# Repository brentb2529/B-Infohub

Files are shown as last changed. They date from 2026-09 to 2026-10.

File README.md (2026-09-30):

# B-Infohub

**Local telemetry from a Briggs & Stratton standby generator — no subscription, no cell modem, no cloud.**

A small ESP32 board that plugs into the RS-485 port your generator already has and
speaks Modbus to its GC-1030/1031/1032 controller directly. Home Assistant gets the
readings in about a second, over your own network.

> The InfoHub is not decoding anything proprietary. It is a Modbus master with a cell
> modem and a billing relationship attached. This becomes the master instead — and you
> can keep the InfoHub connected alongside it if you want the cellular path as backup.

---

## What you get

| | EnergyTrak cloud | B-Infohub |
| --- | --- | --- |
| Readings | 34 | **130+** |
| Freshness | minutes | **~1 second** |
| Faults | one "fault" flag | **34 individually decoded alarms** |
| Works without internet | no | **yes** |
| Subscription | yes | no |

Per-leg voltages and currents, kW / kVA / kVAr, power factor, cumulative energy,
coolant temperature, battery voltage, engine RPM and hours, lifetime starts and trips,
the raw controller status word, and each fault condition as its own entity you can
automate on.

It also records alarms to onboard flash, so a fault that happens while Home Assistant
is down or the network is out is still reported when things come back — the one case
cloud monitoring cannot cover.

## What you need

- A Briggs & Stratton standby generator with a **GC-1030, GC-1031 or GC-1032**
  controller (check the label on the panel).
- A **B-Infohub board** — see [Getting the hardware](#getting-the-hardware).
- Home Assistant, with [HACS](https://hacs.xyz) installed.
- A Chrome or Edge browser on a desktop, once, to flash the board.

No soldering. No toolchain. No command line.

## Install

### 1. Flash the board

Connect it to your computer with a **data** USB cable and open the installer:

### → **[Install B-Infohub](https://brentb2529.github.io/B-Infohub/)**

Click Connect, pick the serial port, and wait. The page will then ask for your Wi-Fi.

<sub>A charge-only USB cable is the most common reason nothing appears in the port list —
it powers the board but carries no data, so the board looks dead to the browser while its
power light is on. Web Serial needs Chrome or Edge; Safari and Firefox do not implement it.</sub>

### 2. Wire it to the generator

**Switch the generator to OFF at the panel first.** Two wires, into the RS-485
terminals the controller already exposes — [wiring guide](docs/wiring.md), including
where the terminals are on each controller and how to keep an existing InfoHub
connected at the same time.

### 3. Add it to Home Assistant

Install the **[EnergyTrak integration](https://github.com/brentb2529/ha-energytrak)**
from HACS, then **Settings → Devices & Services → Add Integration → EnergyTrak**.

The bridge is discovered automatically if it is on the same subnet. On a routed or
VLAN'd network — which includes most setups where the generator is on a different
segment — choose **Local B-Infohub bridge** and enter its IP.

You do **not** need an EnergyTrak account. The integration supports three shapes:

- **Bridge only** — no subscription at all
- **Cloud only** — the original behaviour, no hardware
- **Both** — the bridge is used while it is healthy, and the cloud takes over
  automatically if it is not

## Getting the hardware

The board is built in small batches and is **not sold through a shop**. If you want
one, open a [GitHub issue](https://github.com/brentb2529/B-Infohub/issues) or get in
touch — see the ordering note below.

<!-- ORDERING DETAILS: fill these in before publishing.
     - How should people contact you (issue / email / form)?
     - What is supplied: bare PCB, assembled board, assembled + enclosure?
     - Price, and whether shipping is US-only.
     - Any lead time or batch-size caveat. -->

> **Ordering:** _contact details and what is supplied to be filled in._

Everything needed to have one made independently is in this repository —
schematic, layout, gerbers and a JLCPCB-ready fab package in
[`hardware/pcb/`](hardware/pcb/) — and the firmware is MIT licensed. Buying a board
is a convenience, not a requirement.

## It learns the generator it is plugged into

On first healthy contact the bridge probes the controller once — what it
answers, which alarm inputs are wired — and publishes a **Controller
Profile**. Home Assistant shows the learned family as the device model,
plus *Registers present*, *Alarm inputs indeterminate* and *Commissioned*.
**Run Discovery** repeats it. See [`docs/discovery.md`](docs/discovery.md).

## If something looks wrong

The bridge reports its own health, because a monitor that fails silently is worse
than no monitor:

| Entity | What it means when it is unhappy |
| --- | --- |
| **Bridge reachable** | the board is not answering Home Assistant — power or Wi-Fi |
| **Generator answering bus** | the board is fine; the generator has gone quiet on RS-485 |
| **Controller clock age** | the controller is answering but its clock has stopped — it has hung |
| **Bridge silence** | the board holds its connection but has stopped sending |
| **Wi-Fi Signal** | below about −72 dBm an ESP32 stays associated but cannot be reached |

Those are deliberately five separate signals rather than one "online" flag. They fail
independently and each one points at a different place to look.

There are also five LEDs on the board readable through the lid, which is all you have
standing at the generator with no phone signal. [How to read
them](docs/bring-up.md#status-leds).

## Documentation

| | |
| --- | --- |
| [Wiring](docs/wiring.md) | terminals, cable, termination, keeping the InfoHub |
| [Bring-up](docs/bring-up.md) | first boot, LEDs, proving the bus |
| [Register map](docs/register-map.md) | every address, what it means, what it returns |
| [Field findings](docs/field-findings-2026-08-31.md) | what a real controller actually answers |
| [Development](docs/development.md) | building the firmware, the contract, the tooling |

## Safety and scope

A standby generator is life-safety equipment. This is a **read-only monitor**: it does
not start, stop, or configure anything, and engine control is deliberately not
implemented.

Do not rely on it as your only alerting for anything that matters. It is unofficial,
unaffiliated with Briggs & Stratton, and provided as-is under the MIT licence with no
warranty. Wiring anything into a generator is your responsibility; if you are not
comfortable working in the panel, have an electrician do it.

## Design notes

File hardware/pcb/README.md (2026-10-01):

# B-Infohub Bridge v1.1 — PCB

90 × 92 mm, 2-layer, 1.6 mm FR4. KiCad 10 project generated programmatically from
`tools/circuit.py` and verified with `kicad-cli` 10.0.5.

> **Rev 1.1 (2026-10-01) is the current design**: schematic, board, routing, BOM,
> gerbers and the checks below are all rev 1.1. **It fits the rev 1.0 enclosure
> unchanged** — same outline, same six M3 holes, same three terminals on the top
> edge, same LED light-pipe positions. What changed, and why, is in *Rev 1.1*
> below. Rev 1.0 is the fielded board (one unit, running since 2026-09); its files
> are in git history at tag `pcb-rev1.0`.

## Rev 1.1

| Change | Why |
| --- | --- |
| **ESP32-WROOM-32E-H4 soldered**, replacing the socketed DevKitC | Heat. The fielded unit's die ran 125–135 °F at night and 188 °F in afternoon sun, and at 188 °F the controller link dropped a byte per reply (see *Heat*). The -H4 is the −40…+105 °C grade (the plain -32E is rated to 85 °C — the temperature this board has already reached). The DevKit's AMS1117 (5→3.3 V linear, ~0.3 W inside the module footprint) is gone; the module sits on a via-stitched ground pad. |
| **DE pull-downs** (R16/R17, EE review) | The SP3485's DE input has no pull-down and the ESP's GPIOs float from reset until the firmware runs — and for the whole of a J6 first flash. 10 k on each DE keeps both transceivers in receive, so the board can never drive the generator's bus uncommanded. Rev 1.0 is fielded without them. |
| **Single 3.3 V rail** from an AP63203 | The 5 V rail only ever fed that LDO and the PWR LED. Same buck family, pinout and application circuit as the AP63205 it replaces. |
| **Remote-antenna option**: the same pads take the **-32UE** (U.FL) | Antenna end faces the board edge, so only the enclosure wall is in front of it. Order -32E for the internal antenna; -32UE plus a U.FL→SMA bulkhead pigtail if the box is metal or the signal is poor. |
| **J5 fan header**, 12 V PWM (IO32 → AO3400A), 0.5 A polyfuse, SS14 flyback | Only if shading and venting the enclosure are not enough. Firmware `packages/fan.yaml` runs it from the die temperature, Home Assistant or not. |
| **EN/IO0 support, RESET + BOOT buttons, J6 programming header** | A bare module has no USB bridge; J6 is the one USB-serial flash it ever needs. OTA after that, as before. |
| **R10/R11** fail-safe bias on the InfoHub pair | Carried from the 2026-09-28 source-only change — see *Termination*. |
| LED series resistors moved 75 → 77.5 mm; J4 moved to the left edge | Clearing the module's pad row and the antenna region. LEDs themselves have not moved. |

Replaces the Briggs & Stratton InfoHub as the Modbus master on the GC-1032's RS-485
bus, **while passing the InfoHub through on a second port** so its cell modem keeps
working as out-of-band backup during an outage.

| Check (rev 1.1, 2026-10-01) | Result |
| --- | --- |
| `kicad-cli sch erc --severity-all` | **0 violations** (`binfohub_bridge-erc.rpt`) |
| `kicad-cli pcb drc --severity-all --refill-zones --schematic-parity` | **0 errors, 0 unconnected, 0 parity issues** |
| Routing | **100 %**, 0.25 mm-grid A* router, 738 tracks / 109 vias, GND pour both layers **plotted into the gerbers** (see below) |
| LCSC | **36 distinct parts**, one BOM line each; the 11 parts new or changed in rev 1.1 verified in stock on 2026-10-01, the rest last checked 2026-08-31 |

Remaining DRC output is a handful of warnings: short dangling tails on hand-routed
escape stubs the router joined part-way along (low-speed lines, verified
electrically meaningless in the EE review), and `lib_footprint_mismatch` on the
terminal blocks (locating pegs deliberately stripped, see ORDER.md) and on U1
(the project copy of the WROOM footprint, identical to the library on every
pad, via and keepout). **No silk over any pad, no courtyard overlaps.** The exact
counts are in `binfohub_bridge-drc.rpt`.

**EE review (2026-10-01):** independent pre-fab review of the full source; verdict
*green after fixes*, all applied — -H4 module, DE pull-downs, 680 Ω bias, 1.1 A fan
fuse, 100 nF moved to the VDD pad, BOM grouping by part, JLC gerber layer set.
Confirmed clean: every pin against the firmware map, no strapping pins, EN/IO0
reference circuit, buck pinout and FB, D10/Q2 polarity, SM712 pin order, pour
present in the gerbers, antenna keepout honoured.

> **Rev 1.0's shipped gerbers had no ground pour.** `gen_pcb.py` writes zone
> outlines only, and the rev 1.0 plot never refilled them: the F_Cu gerber in git
> history has zero `G36` regions. The fielded board's GND is tracks only — it works,
> but it is not what the README claimed. `tools/export.sh` now plots with
> `--check-zones` and prints the region count so this cannot silently recur.

Everything is regenerated by `tools/export.sh` after `router.py` (or `rebuild.py`
for text-only changes): ERC, DRC, BOM/CPL, gerbers + drill, the JLC zip and the
previews.

## What is on it

| Block | Parts |
| --- | --- |
| **Power in** | J1 screw terminal, AO3401A reverse-polarity P-FET (4 A — carries the InfoHub too), **SMBJ16A TVS**, 100 µF bulk |
| **3.3 V rail** | AP63203WU-7 sync buck, 3.8–32 V in, fixed 3.3 V 2 A + 10 µH shielded inductor (the b-hydro / rev 1.0 circuit; the datasheet's 3.3 V example is 4.7 µH, 10 µH is the conservative side), 1.1 A polyfuse |
| **InfoHub 12 V** | Separate 2 A polyfuse (F2) |
| **Fan 12 V** | J5, separate 1.1 A / 33 V polyfuse (F3 — a PPTC derates ~40 % at box temperature, so 0.5 A would nuisance-trip), AO3400A low-side PWM switch, SS14 flyback |
| **RS-485 × 2** | SP3485EN transceivers, PSM712 TVS per pair, 120 Ω termination on jumpers (ship OPEN — see below); 680 Ω fail-safe bias R10/R11 on the InfoHub pair; 10 k pull-downs on both DE lines so neither transceiver can drive while the ESP is in reset or being flashed |
| **MCU** | ESP32-WROOM-32E**-H4** (−40…+105 °C grade) soldered, or -32UE for U.FL; 10 k/1 µF on EN, RESET and BOOT buttons, J6 programming header |
| **Indicators** | 5 LEDs (PWR / WIFI / BUS / FAULT / TX) sized for light pipes, plus J4 header |

### Why the power section is split into two fuses

Our bridge draws ~150 mA. The InfoHub's cell modem pulses to 1–2 A on transmit. Sharing
a fuse would let an InfoHub fault take down the telemetry — precisely backwards. Both
legs sit behind the same reverse-polarity FET, so a miswired harness cannot hurt either
device, but a fault in one cannot starve the other.

### Why the LED resistors are 100R / 330R and not 1k

These are driven from a 3.3 V GPIO. A blue or green LED has a forward drop near 2.9 V,
leaving ~0.4 V across the resistor — 1k would give roughly **0.5 mA**, invisible through
a light pipe. 100R for blue/green and 330R for red/yellow puts all five at about 4 mA.

## Termination: ship JP1 and JP2 OPEN

Measured, not assumed. On 2026-08-31 the live bus delivered **368 consecutive
error-free 87-register block reads** (32,016 values, every one CRC-checked) across
engine cranking and five minutes of running, with an adapter that was almost certainly
unterminated. Zero failures.

The physics agrees. At 9600 baud one bit is **104 µs**; signal propagates at ~5 ns/m,
so even a 30 m run has a 150 ns round trip — 0.14 % of a bit period. Reflections from
the SP3485's fast edges settle within a few hundred nanoseconds, while the receiver
samples in the *middle* of the bit. Termination is governed by edge rate versus cable
delay, and here there are three orders of magnitude of margin.

There is also a cost to fitting them: 120 Ω with no fail-safe biasing pulls A and B
together at idle, which can leave the receiver output indeterminate and produce framing
errors. **Adding termination to a bus that already works can make idle behaviour
worse.**

So: leave both jumpers open. Fit one only if CRC errors appear on that segment. They
exist so the option is available, not because it is needed.

If a bus ever does misbehave at idle rather than in traffic, the fix is fail-safe
biasing (pull-up on A, pull-down on B), not termination.

**Rev 1.0 has no bias footprints, and port B does misbehave at idle.** A raw-frame
capture on 2026-09-28 showed ~61 bytes of garbage arriving on the InfoHub pair 35–57 ms
after every reply the bridge sends — the pair floating inside the receiver's ±200 mV
dead band once our driver releases it. ESPHome's Modbus server reads that as an
incoming request, holds its next reply, and drops it: 8 of 36 replies to the InfoHub
in 75 s, with the InfoHub retrying after 0.8 s each time. It tolerates this (it kept
the vendor cloud fed for a week on it), but the bus is dirtier than it should be. Port
A is unaffected because the GC-1032 biases its own bus.

**Rev 1.1 adds R10/R11** (4.7 kΩ pull-up on A to 3.3 V, pull-down on B to GND, next
to U4), fitted by default. Rev 1.0 boards are left as they are by decision; the
firmware can be made tolerant of the noise (flush the port-B receive buffer after
transmitting) if a fielded board ever needs it.

## Heat — measured on the fielded unit, 2026-10-01

The ESP32 die runs **125–135 °F at night** with the air in the 50s: ~75 °F of
self-heating in a sealed box with no airflow. A clear afternoon adds **45–60 °F**
of solar gain on the enclosure (overcast days add 8–17 °F), and the peak is always
13:30–14:45 regardless of the air temperature. On 1 Oct, 80 °F air put the die at
**188 °F**; the port-A link to the GC-1032 then dropped one byte from every reply
(0 good reads for ~90 min, reproduced on a fresh boot at the same temperature) and
recovered on its own as the box cooled. 185 °F on 25 Sep had survived, so the cliff
is ~185–188 °F die. Which end of the link drifts first is not known; the SP3485EN
is industrial grade (−40…+85 °C), the controller is in the same sun.

Firmware 1.2.1 took the two biggest self-heat terms down (CPU 240→160 MHz, Wi-Fi
modem sleep): die fell 192→162 °F in four minutes in the same sun. HA automation
`binfohub_bridge_hot` warns at 175 °F. Neither is the fix; the enclosure is.

**In order of effect:**

1. **Mounting note on the enclosure and in the install guide: not in direct
   afternoon sun.** Shade (a louvered shroud, or the north side of the pad) is
   worth more than every item below combined — it is the ~55 °F term.
2. **A breathing enclosure.** The rev 1.0 box has one membrane vent, low, and
   still reached 188 °F: one vent does not convect. Add a second Gore-type vent
   **high** on the opposite wall so the box is a chimney. Passive; no moving parts
   on a box that must run through an outage.
3. **Done in rev 1.1: bare ESP32-WROOM-32E on the board, 3.3 V straight from an
   AP63203 buck.** The DevKit's AMS1117 LDO dissipated ~0.3 W dropping 5→3.3 V
   inside the module footprint; the module now sits on a via-stitched ground pad
   into the back-side pour.
4. **Fan — provided for, not fitted.** Rev 1.1 carries J5 (12 V, PWM, fused,
   flyback) so a fan can be added without a board change if 1–3 are not enough.
   A fan is a moving part, a dust and moisture path, and a load on the
   generator-side 12 V; a heatsink in still, trapped air moves heat into the same
   air. Neither is the first answer.

Acceptance test: a sunny-afternoon die peak at least 20 °F under the 175 °F
alert, i.e. the rev 1.1 unit should never page.

## Bus parameters — measured, not assumed

**Slave 10, 9600 8E1.** Not the genmon defaults (1 / 19200). Found with
`tools/gc1032_probe.py scan` on 2026-08-31 and confirmed against live readings; the
values are on the back silkscreen so nobody has to re-derive them. See
`../../docs/field-findings-2026-08-31.md`.

## Enclosure interface

The lid needs light pipes over these LED centres (board coordinates, origin = top-left):

| LED | Function | Colour | x | y |
| --- | --- | --- | --- | --- |
| D5 | PWR | green | 18.0 | 80.0 |
| D6 | WIFI | blue | 29.0 | 80.0 |
| D7 | BUS | green | 40.0 | 80.0 |
| D8 | FAULT | red | 51.0 | 80.0 |
| D9 | TX | yellow | 62.0 | 80.0 |

11 mm pitch, which suits 3 mm acrylic rod.

**Cable entry.** All three terminals sit on the **top edge (y = 7)** with their wire
openings facing outward, so one enclosure wall takes every gland. Pad spans:

| Terminal | x range |
| --- | --- |
| J1 12 V IN (2P, 5.08 mm) | 12.0 – 17.1 |
| J2 BUS (2P, 2.54 mm) | 50.0 – 52.5 |
| J3 INFOHUB (4P, 2.54 mm) | 70.0 – 77.6 |

**Terminal contents.** The generator harness carries four conductors that matter:
+12 V, GND, and the RS-485 pair. Power lands on J1, the pair lands on J2 — and J2
needs no ground pin of its own, because the harness ground is already on J1 and it is
the same net. J3 is different: it is a separate cable run out to the InfoHub carrying
power *and* data, so it needs its own return.

| | Pins | To |
| --- | --- | --- |
| J1 | +12V, GND | harness power (red/grey, black) |
| J2 | A, B | harness RS-485 pair (brown, yellow) |
| J3 | +12V, GND, A, B | the InfoHub |

**Mounting:** six M3 holes at (4.5, 4.5), (85.5, 4.5), (4.5, 46), (85.5, 46),
(4.5, 87.5), (85.5, 87.5).

## Files

| File | Purpose |
| --- | --- |
| `binfohub_bridge.kicad_pro/.kicad_sch/.kicad_pcb` | KiCad project |
| `binfohub.kicad_sym`, `binfohub.pretty/` | ESP32-DevKitC-38 symbol + footprint |
| `binfohub_bridge_jlc.zip` | Gerber X2 + Excellon — upload as-is |
| `bom_jlc.csv`, `cpl_jlc.csv` | JLCPCB BOM (verified LCSC numbers) and pick-and-place |
| `ORDER.md` | What to upload, board options, and the loose parts JLC will not place |
| `preview/silk_front-1.png` | Readable silkscreen plot |
| `preview/top.png`, `schematic.pdf` | Render and schematic |
| `tools/` | `circuit.py` is the single source of truth |

Regenerate: `cd tools && python3 gen_libs.py && python3 gen_sch.py && python3 router.py && python3 gen_bom.py`

## Two fixes made to the inherited b-hydro tooling

**`router.py` — trapped-pad escapes.** A pad ringed by its neighbours' keepouts
(SOIC-8 at 1.27 mm, TSOT-23-6) has no free cell for A* to start from. `prelinks`
extended only the *target* set, which helps the far end of a net and does nothing for
the pad that is actually stuck. It now seeds the *source* side too. This took routing
from 11 failures to 0.

**`router.py` — mounting keepouts.** Were hard-coded to b-hydro's 120 × 90 corners, so
two keepouts sat off this board and two real holes had none.

## Before ordering

Not yet reviewed by a second pair of eyes. Specifically worth checking:

- **SM712 pin mapping.** KiCad's `SM712_SOT23` symbol has pin 3 as common; confirm
  against the PSM712 datasheet before fab. Getting it wrong makes the TVS useless.
- Terminal-block orientation (the 180° post-pass in `circuit.py`) — this is the exact
  issue JLC's DFM review flagged on b-hydro.
- AP63205 application circuit against its datasheet, though it is unchanged from a
  board that has already been built.

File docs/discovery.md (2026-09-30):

# Discovery: commissioning a bridge on a generator we have never seen

This bridge was built against one generator and one controller. For it to go
out in the wild, a stranger has to be able to plug it in, join Wi-Fi, add the
integration, and have the generator's capabilities appear by themselves — with
no register knowledge, no laptop probe, and no decisions they are not equipped
to make.

Link settings are fixed for this controller family (9600 baud, even parity,
slave 10). What varies is **what the controller answers, what it means, and
which alarm inputs are wired**. That is what discovery has to learn.

## What already exists

- `tools/gc1032_probe.py` — `scan` / `dump` / `sweep` on a laptop. Read-only
  by construction: holding register `0x0000` starts and stops the engine, so
  there is no write function anywhere in the file.
- `packages/holding-sweep.yaml` — on-device probing, and the record of how it
  fails. Its first version interleaved probe reads with the normal poll loop;
  responses were matched to the wrong requests and telemetry — so the alarm
  pipeline — was down within four minutes. The fix, and the envelope every
  on-device probe must inherit:
  - **take the bus exclusively** (`stop_poller()` / `start_poller()`);
  - **refuse to run while the engine turns**;
  - **watchdog under the 5-minute bridge-dark threshold**, so a probe can
    never page anyone;
  - **no per-register entities** — the board runs at ~81% RAM and heap
    exhaustion has already caused an aborted boot and an automatic rollback;
  - **never a write.** Only function codes 0x03 and 0x04 are constructed.
- **Passthrough is already safe to probe alongside.** Port A faces the
  generator; port B answers the InfoHub as a slave from reconstructed values,
  never from the wire. A probe on port A cannot collide with the InfoHub, and
  registers we do not model are already served as `0xFFFF` — the controller's
  own "not present".

Discovery is a generalisation of `holding-sweep`, not new machinery.

## The commissioning flow

Zero user decisions on the default path.

1. **Flash** from the web installer; **Wi-Fi** via Improv (Bluetooth or the
   USB cable); **HA adopts it** through EnergyTrak's discovery.
2. **The first time `bus_healthy` goes true with the engine stopped, the
   bridge commissions itself.** Four read-only steps inside the sweep's
   envelope:
   - **Identity** — protocol revision (`0x0000`) and model registers →
     controller family.
   - **Presence** — attempt each documented range. A Modbus *illegal address*
     exception means the register genuinely is not there; a *timeout* means
     wiring or link. These must never be conflated.
   - **Plausibility** — sanity-check decodes against physical ranges (battery
     8–16 V, frequency 0/50/60 Hz) so a range that answers with nonsense is
     marked present-but-implausible rather than trusted.
   - **Alarm baseline** — sample `0x0040`–`0x004D` at rest and record every
     nibble. See `alarm-encoding.md` for why this is an inventory, not a
     decode.
3. **The profile is stored in flash and published** as one compact value plus
   a few scalars — never per-register entities.
4. **The poller narrows** to the ranges that answered, so absent registers
   stop dragging `bus_success_rate` down and looking like a fault.
5. **Passthrough is offered only after commissioning** — which is already how
   it behaves: off by default, never restored on.

### Re-probe triggers

- The profile's schema version changes (after an OTA that adds knowledge).
- The identity registers change (a controller was replaced).
- A **Re-run discovery** button, for after a wiring change.

Never automatically while the engine turns, and never during an outage.

## The alarm baseline, and the one thing that cannot be automated

The baseline is only meaningful if the generator is healthy when captured.
Commission during a real fault and the baseline would memorise that fault as
normal — the monitoring would then be silent about the one thing it exists to
catch.

Handled without asking the user anything:

- capture only when the engine is stopped, no shutdown bits are asserted and
  utility power is present;
- mark the baseline **provisional**;
- confirm it automatically after the first complete run that ends with no
  faults;
- publish `baseline_captured_at` and the provisional flag, with a **Recapture
  baseline** button for after a controller swap.

The default path is silent; the risky case is stated rather than hidden.

### What the baseline records

Not "which conditions are faults" — we do not know the encoding well enough
to say that. It records **every condition's raw nibble** and its four-state
classification from `alarm-encoding.md` (not present / ok / indeterminate /
fault). Indeterminate conditions are listed to the user explicitly: *read 0 on
a healthy machine, not treated as a fault, raw value shown.* On someone else's
generator that is the difference between a confusing screen of phantom faults
and an honest inventory.

## The profile

Published by the firmware; carried by the contract as a new `capabilities`
section (schema in one place, both transports agreeing, exactly as `controls`
works today); read by EnergyTrak, which duplicates no decode logic.

```json
{
  "schema": 1,
  "family": "gc103x",
  "identity": {"protocol_revision": "0x8003"},
  "captured_at": "2026-09-27T21:00:00Z",
  "ranges": {
    "0x0000-0x0027": "present",
    "0x0029-0x002B": "present",
    "0x0033-0x0036": "present",
    "0x0038-0x003D": "present",
    "0x0040-0x0056": "present"
  },
  "implausible": [],
  "alarm_baseline": {
    "block": "11001111FF111111F0F0111F0100001110011111000000F011F1111FE",
    "provisional": false,
    "confirmed_by_run_at": "2026-10-03T13:50:00Z"
  }
}
```

EnergyTrak uses it for three things: the model on the device card, a
`Controller Profile` diagnostic, and defaulting indeterminate alarm entities
to disabled. It already creates entities only for fields actually reported,
so it needs no per-model tables.

## What has to change

| Where | Change |
|---|---|
| Firmware | a `commissioning` package modelled on `holding-sweep.yaml`: identity, presence, plausibility, baseline; profile in flash prefs; `Re-run discovery` and `Recapture baseline` buttons |
| Firmware | the poller reads its range list from the profile rather than from compile-time YAML |
| Firmware | the **proxy's slave address follows discovery** — it is a compile-time substitution today, and an InfoHub on a family that uses a different address would not see its generator |
| Contract | `capabilities` section, generated the way `controls` is |
| EnergyTrak | read the profile; device card, diagnostic entity, disabled-by-default for indeterminate alarms |

## Unknown controllers

Fail soft. A family the vendor JSON does not describe gets "unknown
controller — raw registers only, no derived alarms" rather than a guessed
decode. This project has been self-consistent and wrong twice already (the
timezone bug; the 94-minute controller clock). Presenting inferred values as
fact is the failure mode to design against.

## What to ship first

Not autodetect. A **guided setup that verifies and reports**: the installer
accepts the link settings, the bridge probes once, and states plainly —
*controller answering at 9600/EVEN/10, 87 registers present, 15 alarm inputs
indeterminate, baseline captured (provisional)*. That is most of the value,
keeps the bus-exclusive risk to one deliberate action, and produces the first
profile from someone else's generator — which is itself the data this design
is missing.

## The honest caveat

There is one generator and one controller. Everything about other families is
inference until a stranger's board reports a profile. That is an argument for
shipping the profile early, not for waiting.

## Status — 2026-09-29: commissioning is implemented and verified

`packages/commissioning.yaml` runs once, by itself, the first time the bus is
healthy with the engine stopped and no profile is stored, and again on the
**Run Discovery** button. Verified on the real GC-1032: family `gc103x`,
protocol `0x8003`, firmware `0x4113`, model register absent, **87 registers
present** (the same 87 the August laptop sweep found), alt block absent, alarm
inventory 8 absent / 30 ok / 17 indeterminate / 1 unexpected; identical on a
second run and after a reboot; bus impact 1 missed poll. ha-energytrak
≥ 1.26.1 reads it (device model, Controller Family, Registers Present, Alarm
Inputs Indeterminate, Commissioned) and applies the four-state alarm rule.

### What the wire taught, and the code now assumes

- An ESPHome custom command's frame **includes the slave address**; the
  callback receives **register bytes only**; the hub **de-duplicates
  byte-identical frames** (the heartbeat reads two registers so it cannot be
  absorbed into the poller's own read of 0x0000); `send_wait_time` is 2000 ms
  by default and is set to 500 ms for the probe's duration; misses are pooled
  per controller and past `max_cmd_retries` the controller is marked offline
  and its queue cleared — so the probe runs with retries at zero, one command
  in flight, and a heartbeat after every miss. `stop_poller()` stops new
  cycles; the one already queued drains for ~12 s first.
- Only what the poller does not read is probed. The poller's own ranges are
  proven present by their sensors having values, except 0x0033–0x0036, whose
  senders are absent here (all 0xFFFF → NaN) and which is probed directly.
- On this controller an absent register answers **illegal data address in
  12 ms**, so "did not answer" never arose; the design still tolerates it.
- **Home Assistant caps a sensor state at 255 characters.** The profile is
  one string; v1 was ~330 and read `unknown`. v2 is ~237.
- **RAM:** the five-entity first cut aborted on boot (API overflow buffer
  allocation with two clients connecting). Two entities now; +0.6 % RAM.

### Profile v2 (the `Controller Profile` text sensor)

```json
{"v":2,"fam":"gc103x","proto":"8003","fw":"4113","model":"FFFF","n":87,
 "map":"FFFFFFFFFFFFFFFF007FFFFF00000000","alt":"00000000",
 "base":"11001111FF111111F0F0111F010000111001111100000F011F1111FE",
 "prov":1,"batt":1,"util":1,"t":1790737519}
```

| Key | Meaning |
|---|---|
| `fam` | `gc103x` when `proto` is 0x8003 and 0x0040–0x004F are present; otherwise `unknown` |
| `proto` / `fw` / `model` | registers 0x0000 / 0x0055 / 0x00B5 as hex words; `FFFF` = did not answer |
| `n` | registers present |
| `map` | presence bitmap for 0x0000–0x007F, four 32-bit words, MSB first |
| `alt` | presence bitmap for 0x00B4–0x00D3 |
| `base` | 0x0040–0x004D as read at commissioning, four hex digits each |
| `prov` | baseline provisional (no clean run confirmed it yet) |
| `batt` / `util` | battery 8–16 V; utility 0 or 90–140 V per leg |
| `t` | Unix time of capture, 0 if the clock was not valid |

The contract carries `alarm_bits` (register, mask, asserted value per alarm)
so a consumer can apply the four-state rule against `base` without the
device decoding anything.

### Not yet done

- Narrowing the poller to present ranges (Phase 3) and the provisional →
  confirmed baseline transition after a clean run.
- The first profile from a second generator. The friend's unit is the
  candidate; its August cloud dump predates the raw blocks.

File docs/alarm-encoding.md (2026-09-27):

# The alarm block: what we know, what we assumed, and how to find out

Every alarm entity this firmware publishes is a nibble test against input
registers `0x0040`–`0x004F`, decoded by one rule from genmon's controller
definition: **asserted when `(raw & mask) == value`**, with the fault nibbles
**active low** — a nibble of `0` means the fault is present.

That rule has never been confirmed on this hardware. **No real alarm has ever
been observed on this generator**, in the registers or anywhere else. This
document records why the rule is now in doubt, what the evidence actually
supports, and the two safe tests that would settle it.

## What the evidence says

### 1. The block does not move

`captures/run-2026-08-31.csv` holds 368 samples across a full manual start,
run and stop. Registers `0x0040`–`0x004D` are **bit-for-bit identical in every
sample**. Only `0x004E` and `0x004F` change — and those are the engine-state
and status words, ordinary active-high bits.

Static across an engine cycle is what *configuration* looks like, not live
alarm state.

### 2. The nibble alphabet is tiny

Across every sample, the only values that appear in `0x0040`–`0x004D` are
`0`, `1`, `0xE` and `0xF`. The baseline capture (`vendor/baseline-2026-08-31.json`):

| Register | Value | Nibbles |
|---|---|---|
| 0x0040 | 0x1100 | 1 1 0 0 |
| 0x0041 | 0x1111 | 1 1 1 1 |
| 0x0042 | 0xFF11 | F F 1 1 |
| 0x0043 | 0x1111 | 1 1 1 1 |
| 0x0044 | 0xF0F0 | F 0 F 0 |
| 0x0045 | 0x111F | 1 1 1 F |
| 0x0046 | 0x0100 | 0 1 0 0 |
| 0x0047 | 0x0011 | 0 0 1 1 |
| 0x0048 | 0x1001 | 1 0 0 1 |
| 0x0049 | 0x1111 | 1 1 1 1 |
| 0x004A | 0x0000 | 0 0 0 0 |
| 0x004B | 0x0F01 | 0 F 0 1 |
| 0x004C | 0x1F11 | 1 F 1 1 |
| 0x004D | 0x11FE | 1 1 F E |

Under the active-low rule, this healthy, idle generator has roughly fifteen
faults asserted. `0x004A` reading `0x0000` would be four simultaneous faults;
it looks far more like an unimplemented register.

### 3. The controller's own manual

The GC1031 operator's manual (Tables 5–7) adds two facts the decode never
accounted for:

- **Every alarm has a configurable action** — None / Notification / Warning /
  Electrical Trip / Shutdown — set per input, per battery threshold, per
  maintenance alarm. If the nibbles were those action codes we would expect
  `2`, `3` or `4` somewhere: low oil pressure ought to be a Shutdown. None
  appear.
- **A missing sensor is its own alarm**: "Anlg LOP (Pin 26) Ckt Open — the oil
  pressure sensor is detected as not being present." Absence is reported
  explicitly. That undercuts the inference this project made to explain the
  fifteen "faults" — that a zero nibble also means an unpopulated input. That
  inference was never verified either.

The manual maps LCD messages to conditions. It says nothing about Modbus
beyond slave id and baud. **No public document maps this controller's
registers to its display**, and genmon's definition carries no display codes.

### Where that leaves us

Neither theory fits the data:

- *Active-low live flags* — contradicted by a block that never moves and by
  fifteen phantom faults on a healthy unit.
- *Configured action codes* — contradicted by the absence of any 2/3/4.

The encoding is **unknown**. Stated plainly: **the critical alarm path may
never fire, and nothing would say so.** What keeps the system from being
blind is the design rule already applied to the alerts that matter most —
`power_out_no_generator` and `bridge_dark` observe facts (utility down, engine
not turning; bridge silent) rather than asking the controller to diagnose
itself.

## What the firmware does about it now

`packages/alarm-watch.yaml` decodes nothing. It publishes the raw block as one
string, counts changes to it, and flags any nibble value never seen before.
Whatever the encoding is, a controller raising an alarm is unlikely to leave
all fourteen registers untouched — and if it does, that is itself the answer,
established rather than assumed.

The three entities:

| Entity | Meaning |
|---|---|
| `Alarm Block` | `0x0040`–`0x004D` as 56 hex characters, MSB first. `incomplete` until every register has arrived — never `0000` in its place. |
| `Alarm Block Changes` | Count since boot. Expected reading: 0. |
| `Alarm Block Unexpected Value` | A nibble outside `{0, 1, E, F}` has appeared. |

The alert this feeds is honest about its ignorance: *the alarm block changed;
read the display.*

## The four-state model this argues for

Stop treating the absolute value as the signal; treat the **transition** as
the signal. Per condition:

| Observed | Meaning | Published as |
|---|---|---|
| `F` | not present — the controller's own absence encoding (`0xFFFF` is used the same way for absent phases) | not present |
| `1` | wired and OK — proof the input exists | ok |
| `0` since commissioning | **indeterminate**, shown as such, never silently dropped, never counted as a fault | indeterminate, with the raw value |
| `1` then `0` | fault — an observed change no interpretation can explain away | fault |

It self-calibrates: the first time a nibble reads `1`, that condition is
proven wired, and from then on its zero means something. The one gap — a
fault already asserted before commissioning looks indeterminate — is exactly
the case to surface, not hide.

## How to settle it

Ranked by safety. The first two need nothing but patience; the third is the
one that gives an answer on demand.

1. **Passively.** The flash event log and `Alarm Block Changes` capture the
   first real event whenever it comes.
2. **Mild natural conditions.** Maintenance-due or low-battery warnings occur
   on their own and can be verified in the InfoHub app at the same time.
3. **The controller's own benign alarms, from its menus.** No engine
   intervention, nothing disconnected, fully reversible. Capture the block
   before and after each:
   - `MAINTENANCE → DUE AT ENGINE HOURS`: set below the current hours (they
     read 94.9 on 2026-09-26), action Notification. The controller raises a
     real alarm and displays it. Restore afterwards.
   - `BATTERY MONITOR → LOW VOLT THRESHOLD`: set just above the actual battery
     voltage (~13.1 V), action Notification, delay at minimum. Restore.

   If the LCD shows an alarm and nothing in `0x0040`–`0x004D` moves, the
   decode is reading something other than live state, and the alarm entities
   must be rebuilt around whatever did move. If a nibble goes `1 → 0`, the
   active-low rule is confirmed and the zero-at-rest conditions are the
   unpopulated inputs after all.

4. **A sender disconnect** (selector OFF, engine cold, InfoHub unplugged) is
   decisive but is a physical intervention on life-safety equipment. Owner's
   call.

Whatever the outcome, record it here with the register values, and update
`tools/gen_alarms.py` to match what was observed rather than what was
documented.

## Sources

- genmon controller definition: `vendor/Briggs_Stratton_GC-1032.json`
- GC1031 GENSET Controller Operation Instructions (Briggs & Stratton),
  Tables 5–7 — https://norwall.com/content/norwall-pim-app/assets/document/8878_GC1031_Operators_Manual.PDF
- genmon Appendix P — https://github.com/jgyates/genmon/wiki/Appendix-P-Briggs-and-Stratton-Controller-Information
- `captures/run-2026-08-31.csv`, `vendor/baseline-2026-08-31.json`

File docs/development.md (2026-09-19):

# B-Infohub — development notes

> This is the original bring-up log, kept for anyone working ON the bridge
> rather than installing one. For installation see the [README](../README.md).
>
> Parts of it are historical and no longer accurate: the firmware has since
> been flashed and run on a live generator, the alarm set was filtered from 51
> raw bits down to the 34 that are meaningful on a split-phase unit, and the
> nine `raw_0x00XX` research sensors were removed to free heap. Read it as a
> record of how the decoding was established, not as current state.

## Goal

Replace the Briggs & Stratton InfoHub with a local ESP32 + RS-485 bridge that speaks
Modbus RTU directly to the **GC-1030/1031/1032** controller. No cell modem, no
subscription, no cloud round-trip — and considerably more data than the InfoHub ever
surfaced.

The InfoHub is not decoding anything proprietary. It is a Modbus master with a cell
modem and a billing relationship attached. This project just becomes the master
instead.

**What you get over the InfoHub:** per-phase voltages, currents, kW, kVA, kVAR and
power factor; cumulative kWh; oil pressure, coolant temp, battery voltage, RPM;
lifetime starts, trips and run hours; **51 individually decoded fault conditions**
instead of one "fault" flag; the raw status word; and optional start/stop/auto control.

~146 entities, all local, all in Home Assistant.

## Status

| Piece | State |
| --- | --- |
| Register decoding | **Validated against the real controller**, 2026-08-31 |
| ESPHome firmware, read-only | `esphome config` clean; decodes proven on live data, **not yet flashed** |
| Control (start/stop/auto) | Written, validates, **gated off by default** — see below |
| Bench probe tooling | Written, read-only by construction, **exercised end-to-end against a simulator** |
| Decoder tests | `tools/test_decoders.py` — 50 alarm decoders + status word, all passing |
| HA → Grafana push | Written, follows the existing B-Panels pipeline |
| Grafana dashboard | Generated, 27 panels |

The probe has been run end to end against `tools/fake_gc1032.py`, a simulated
controller on a pseudo-terminal: `scan`, `dump` and `sweep` all behave correctly,
including skipping the dead address holes and surfacing undocumented registers that
change between passes. `tools/test_decoders.py` evaluates all 50 generated alarm
lambdas plus the status word against known register states.

What a pty cannot test: baud/parity detection (line settings are ignored, so `scan`
matches every combination), bus turnaround, and anything electrical.

**2026-08-31: first contact with the real controller — it works.** Bus parameters
found, all 87 registers read, a full start/run/stop cycle captured at 1 Hz, and three
firmware bugs found and fixed against live data. See
[`docs/field-findings-2026-08-31.md`](docs/field-findings-2026-08-31.md).

Still untested: the control (write) path. The register map is genmon's, which is
well-proven, but every decode in `packages/gc1032-status.yaml` should be confirmed
against one exercise cycle before you trust it.

## Repo layout

| Path | Purpose |
| --- | --- |
| `genset-gc1032.yaml` | Device config — ESP32-DevKitC + MAX485. Start here. |
| `packages/base.yaml` | Wi-Fi / API / OTA / web / Improv / mDNS / diagnostics |
| `packages/mqtt.yaml` | MQTT alongside the native API (discovery deliberately off) |
| `packages/gc1032-power.yaml` | Electrical measurements, 0x0000–0x002C |
| `packages/gc1032-engine.yaml` | Engine, fuel, battery, runtime, clock |
| `packages/gc1032-status.yaml` | Raw fault registers + status-word decode |
| `packages/gc1032-alarms.yaml` | **Generated** — 51 fault entities |
| `packages/gc1032-control.yaml` | **DANGEROUS** — start/stop/auto. Not included by default. |
| `tools/gc1032_probe.py` | Read-only bench probe for the FTDI USB-RS485 cable |
| `tools/adapter_check.py` | Bench-checks the USB-RS485 adapter with nothing connected |
| `tools/fake_gc1032.py` | Simulated GC-1032 on a pty — test the probe with no generator |
| `tools/test_decoders.py` | Verifies the generated alarm/status decoders against known states |
| `tools/gen_alarms.py` | Regenerates the alarms package from the register map |
| `tools/gen_dashboard.py` | Regenerates the Grafana dashboard |
| `ha/packages/` | Home Assistant: metric attributes + Grafana Cloud push |
| `grafana/dashboards/` | **Generated** dashboard JSON |
| `vendor/` | Pinned genmon register map + provenance |
| `docs/wiring.md` | FTDI hookup, ESP32 wiring, 12 V power front end, grounding |
| `docs/register-map.md` | Register tables and the four traps |
| `docs/field-findings-2026-08-31.md` | **What the real hardware actually did** — read this |
| `captures/` | Live captures: full run cycle at 1 Hz, sweeps, at-rest dumps |

## Bring-up order

Do these in order. Each step de-risks the next.

### 1. Prove the bus exists (no soldering, no ESP32)

You already have the FTDI USB-RS485 cable. Wire it per
[`docs/wiring.md` §2](docs/wiring.md) — and note the colour collision: the FTDI cable
has a yellow wire and so does the generator harness, and they are different signals.

```bash
pip install pyserial
ls /dev/cu.usbserial-*                                   # NOT /dev/tty.* -- see docs/wiring.md
python3 tools/adapter_check.py --port /dev/cu.usbserial-XXXXXXXX   # do this at the desk first
python3 tools/gc1032_probe.py scan --port /dev/cu.usbserial-XXXXXXXX
```

`adapter_check.py` verifies the port and settles whether your adapter needs RXD+/RXD-
jumpered, without the generator being involved at all. **Already run for this
adapter** (`/dev/cu.usbserial-A94C31KL`): it is full-duplex RS-422 silicon and **needs
the jumpers** — RXD+ to T/R+, RXD- to T/R-, both joined pairs going to bus A and B.
See `docs/wiring.md`.

`scan` brute-forces baud, parity and slave id and never writes anything. The full
240-combination sweep takes about **35 seconds**. If it finds
nothing, swap A and B and run it again before concluding anything.

Then see what is actually there:

```bash
python3 tools/gc1032_probe.py dump  --port /dev/cu.usbserial-XXXXXXXX --baud 19200 --parity N
python3 tools/gc1032_probe.py sweep --port /dev/cu.usbserial-XXXXXXXX --baud 19200 --parity N
```

`sweep` is the one that answers "the controller must know more than the InfoHub told
me" — it probes the whole low address space twice and reports which **undocumented**
registers respond and which of them moved. Run it again during an exercise cycle.

### 2. Build the bridge

Set `modbus_baud`, `modbus_parity` and `modbus_address` in `genset-gc1032.yaml` to
whatever step 1 found.

```bash
python3 -m venv .venv && .venv/bin/pip install esphome
cp secrets.yaml.example secrets.yaml     # then fill it in
.venv/bin/esphome run genset-gc1032.yaml # USB the first time, OTA after
```

### 3. Confirm the decodes before trusting the dashboard

Watch `Status Register Raw` through one full exercise cycle. Expect `0x6800` at rest
and `0x7100` while exercising. If those do not match, fix
`packages/gc1032-status.yaml` before wiring up alerts.

Also sanity-check `Percentage Load` under real load — genmon's own map is internally
inconsistent about whether it needs a ×0.1 scale, and the sensor carries a comment
saying so.

### 4. Grafana

Copy `ha/packages/*.yaml` into `<config>/packages/`, then import
`grafana/dashboards/b-infohub-genset.json`.

**Verify the entity ids first.** `ha/packages/b_infohub_customize.yaml` is the one file
that must name entity ids, and it assumes `sensor.genset_*`. If HA assigned a `_2`
suffix, the customize entries bind to nothing — silently, because customize does not
warn about unknown ids. Developer Tools → States, filter on `genset`.

The push writes a **`genset_*`** measurement, deliberately separate from the existing
`generator_*` series that B-Panels' cloud poller produces. Both dashboards run side by
side. See the header of `b_infohub_customize.yaml` for why colliding on the same
attribute namespace would have silently corrupted the old dashboard rather than
failing loudly.

## Control is off by default

`packages/gc1032-control.yaml` can start and stop the engine, and on some
installations actuate the transfer switch. It is behind two interlocks:

1. The include in `genset-gc1032.yaml` is commented out.
2. A **Generator Control Enabled** switch that defaults off and is *not* restored
   across reboots.

Leave it read-only until the telemetry has been right for a while. There is no hurry:
reading is the whole value proposition, and writing is a five-minute uncomment
whenever you want it.

## Things that will bite you

- **One master.** The InfoHub must come off the RS-485 pair. Two masters means
  collisions and an InfoHub reporting comm faults to your dealer.
- **You lose the cell modem.** The generator runs when the grid is down, so the
  network path has to survive the outage too. **Resolved for this install: the house
  is on UPS.** LAN-side monitoring (bridge → AP → Home Assistant) therefore keeps
  working through an outage. Remote viewing additionally depends on the ISP's own
  equipment staying up, which is outside the UPS.
- **Alarms are active low.** A nibble of `0x0` means the fault *is* present.
- **The address space has holes that time out.** See `docs/register-map.md`.
- **Cranking browns out cheap buck converters.** Use a wide-input part; see
  `docs/wiring.md` §4.

## Credit

The register map is [genmon](https://github.com/jgyates/genmon)'s
`Briggs_Stratton_GC-1032.json` — pinned in `vendor/` with provenance. Without it this
would have been a logic-analyzer project.

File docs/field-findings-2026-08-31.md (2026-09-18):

# Field findings — 2026-08-31

First contact with the real controller. Everything below is measured, not inferred.
Where it contradicts genmon or my own earlier assumptions, the hardware wins.

## Bus parameters

**Slave id 10, 9600 baud, 8E1.** Not the genmon defaults (1 / 19200 / none) that this
repo originally shipped. `tools/gc1032_probe.py scan` found them in 35 seconds.

A detail worth keeping: parity `N` failed while both `E` and `O` matched. That is the
signature of an 8E1 device — pyserial does not reject parity errors, so E and O deliver
identical data bytes and only the (ignored) check differs. Two hits is the expected
result here, not an ambiguity.

## The register space is smaller than the map suggests

Swept 0x0000–0x02FF (768 addresses). **87 registers respond, all within 0x0000–0x0056.**
Nothing above 0x0056 answers. genmon's `alt_input_registers` block reaching to 0x00C1
does not exist on this unit.

`0x00B5` (Controller Model) is the only documented register that does not respond —
exactly as genmon warns. Keep it excluded.

The "holes" are not holes here: 0x002D–0x0032, 0x0037 and 0x003E–0x003F all respond,
returning 0xFFFF. They are exposed raw and disabled by default in
`packages/gc1032-unmapped.yaml`.

**Holding registers: zero response.** FC03 across 0x0000–0x01FF returned nothing at
all. There is no readable configuration space. This retroactively justifies using
ESPHome's write-only `output` platform for control rather than the `number` platform —
`number` would poll-read holding 0x0000 and time out on every cycle.

## 0xFFFF means "sensor not present"

Oil pressure (0x0033), fuel level (0x0035), fuel volume (0x0036) and every L3 register
return 0xFFFF. Unfiltered that publishes **6553.5 V** on Generator L3. All sensors now
filter it to NAN → unavailable, except the raw alarm registers where 0xFFFF is the
legitimate healthy state.

Oil pressure stayed 0xFFFF **at 2800 RPM under load-free running**, which proves the
sender is absent rather than merely idle-zero.

## Alarms: active-low is right, but 0 also means "not fitted"

15 of 51 conditions asserted on a demonstrably healthy generator. Every one is an
unpopulated input: fuel level/theft/cap (gas unit, no tank), water level and
oil-pressure-open (air-cooled), L3 and phase rotation (single-phase), and unwired aux
inputs A/B/F/G/I.

The polarity was never wrong. The problem is that a nibble of 0 encodes both "faulted"
and "not applicable". Healthy-state registers are captured in
`vendor/baseline-2026-08-31.json`; `tools/gen_alarms.py` reads it and marks anything
asserted at baseline as `disabled_by_default` rather than deleting it.

**Re-capture the baseline if a sensor is ever fitted**, or that input stays hidden.

## The status word is flags, not an enum

genmon models 0x004F's high bits as a 0x7F00 enum with six values. Observed run
produced **0x6080** and **0x6100**, neither of which is in it — the entity would have
read "Unknown" for the entire test.

Decomposition, confirmed against genmon's own six values:

| Bit | Meaning |
| --- | --- |
| 0x4000 | utility healthy |
| 0x1000 | called to run |
| 0x0800 | **Auto mode selected** |
| 0x0200 | producing power |
| 0x0100 | engine running |
| 0x0080 | engine stopped |
| 0x0040 | stopped with fault |
| 0x0008 | common shutdown |

The 0x7F00 mask straddles the running bit at 0x0100, which is precisely why unobserved
combinations fall through. `packages/gc1032-status.yaml` now honours genmon's six
labels when the word matches exactly, and composes from flags otherwise.

Observed sequence:

| Time | Word | State |
| --- | --- | --- |
| 17:55:15 | `0x6880` | utility + auto + stopped — idle in AUTO |
| 17:55:31 | `0x6080` | utility + stopped — MANUAL selected at panel |
| 17:55:40 | `0x6100` | utility + running — running in MANUAL |
| 18:02:14 | `0x6080` | stopped |
| after | `0x6880` | back to AUTO, matches pre-test exactly |

No separate cool-down state appeared on a manual stop.

## Decodes confirmed against reality

- **Date/time byte packing** — 0x0052 = `0x081F` → month 8, day 31; 0x0053 = 2026.
  Correct. 0x0050's high byte ticked 0x11 → 0x12 during the sweep: minutes confirmed.
  (Controller clock runs ~1.5 h behind wall time — drift, not a decode error.)
- **Starts counter** — 279 before, **280** after. Arithmetic proof of the decode.
- **0x004E is dual-purpose** — bit 0x0010 (Fuel Relay Open) set on start, cleared on
  stop. Its low nibble also differs by mode (0x7 in Auto, 0x1 in Manual).
- **Battery dipped to 11.4 V on crank**, recovering to 13.4 V. This is the brownout the
  wide-input buck in `docs/wiring.md` §4 exists for — measured, not theoretical.
- **Low-speed test mode is normal** for this unit: 2802 RPM / 46.7 Hz / 180 V, held
  steady with no faults. Confirmed by the owner. Do not alarm on off-nominal frequency
  without checking mode first.

## Two bugs the hardware found

**Local echo.** The RS-422 adapter with RXD jumpered to T/R hears its own transmission.
The probe consumed those 8 bytes as the response, failed CRC, and reported "nothing
responded" while the real reply sat unread. The tell was *timing*: the failing scan ran
in 9.5 s instead of 34.5 s, because every transaction returned instantly on the echo
instead of waiting out its timeout. **A sweep that gets faster is a sweep that stopped
listening.**

**argparse ordering.** `probe.py scan --port X` failed with "unrecognized arguments"
because the common options lived on the top-level parser. It was the exact command the
README told you to run. Common options now sit on a shared parent parser.

## Still untested

The **control path**. `packages/gc1032-control.yaml` validates but has never written to
this controller. Holding registers do not read back, so a write can only be confirmed
by side effect. Test it deliberately, from the ESP32, with the interlock armed — not
from an ad-hoc script.

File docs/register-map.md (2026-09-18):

# GC-1032 register map

Everything here is derived from `vendor/Briggs_Stratton_GC-1032.json` (genmon). That
file is the source of truth; this page is the human-readable version plus the traps.

## The four things that will cost you an afternoon

1. **Function code 04, not 03.** All telemetry lives in *input* registers. Reading them
   as holding registers (FC03) returns nothing useful. In ESPHome this is
   `register_type: read` — which is confusingly named, but it is FC04.

2. **The alarm nibbles are ACTIVE LOW.** A nibble reading `0x0` means the fault **is**
   asserted. Every alarm in genmon is encoded as mask `f000` with value `0000`. Get
   this backwards and your dashboard shows 47 active faults on a healthy generator, or
   worse, shows all-clear during a real one.

3. **There are holes in the address space, and they time out.** `0x002D–0x0032`,
   `0x003E–0x003F`, and `0x00B5` (Controller Model) do not respond on all units, and a
   timeout stalls the whole polling loop. The packages use `force_new_range: true` at
   `0x0033`, `0x0040` and `0x0050` to stop ESPHome merging reads across those gaps.
   **Do not remove those without re-reading this section.**

4. **Start is a two-write sequence.** `0x0001` (Manual) then `0x0002` (Crank). A lone
   `0x0002` does nothing, which makes a half-working control implementation look like
   a wiring fault.

## Control — holding register 0x0000 (FC06)

| Write | Effect |
| --- | --- |
| `0x0001` | Manual mode — this is also the **Stop** command |
| `0x0002` | Crank/Start — only valid immediately after a `0x0001` |
| `0x0004` | Auto mode |

On some installations these also actuate the transfer switch. Assume yours does.

## Status word — input register 0x004F

| Mask | Value | Meaning |
| --- | --- | --- |
| `0x7F00` | `0x3900` / `0x3B00` / `0x6800` / `0x6900` / `0x6B00` / `0x7100` | Initialized / Generating / Off-Ready / Cool Down / Shutdown Pending / Exercising |
| `0x3800` | `0x2000` / `0x2800` / `0x3000` / `0x3800` | Manual / Automatic / Scheduled Exercise / Initialized |
| `0x0100` | set | Engine running |
| `0x0080` | set | Stopped |
| `0x0040` | set | Stopped with fault |
| `0x4000` | set = healthy, clear = **failure** | Utility power |
| `0x8000` | set | Controller in config mode |
| `0x0008` | set | Common shutdown |

Expect `0x6800` at rest and `0x7100` during a scheduled exercise. Watch the
`Status Register Raw` entity through one full exercise cycle before trusting any
decode above — this table is inferred, not from a B&S document.

`0x004E` is dual-purpose: genmon calls it "Alarm Register 15" but also reads engine
state from it (`0x0010` fuel relay open, `0x0020` starting). Those two bits are
ordinary **active-high**, unlike the fault nibbles.

## Input registers (FC04)

| Reg | Words | Scale | Name |
| --- | --- | --- | --- |
| `0x0000` | 1 |  | Protocol Revision |
| `0x0001` | 1 | ×0.1 | Generator L1 Voltage |
| `0x0002` | 1 | ×0.1 | Generator L2 Voltage |
| `0x0003` | 1 | ×0.1 | Generator L3 Voltage |
| `0x0004` | 1 | ×0.1 | Generator L1-L2 Voltage |
| `0x0005` | 1 | ×0.1 | Generator L2-L3 Voltage |
| `0x0006` | 1 | ×0.1 | Generator L3-L1 Voltage |
| `0x0007` | 1 | ×0.1 | Generator L1 Frequency |
| `0x0008` | 1 | ×0.1 | Generator L2 Frequency |
| `0x0009` | 1 | ×0.1 | Generator L3 Frequency |
| `0x000A` | 1 | ×0.01 | L1 Power Factor |
| `0x000B` | 1 | ×0.01 | L2 Power Factor |
| `0x000C` | 1 | ×0.01 | L3 Power Factor |
| `0x000D` | 1 | ×0.01 | Average Power Factor |
| `0x000E` | 1 | ×0.1 | Utility L1 Voltage |
| `0x000F` | 1 | ×0.1 | Utility L2 Voltage |
| `0x0010` | 1 | ×0.1 | Utility L3 Voltage |
| `0x0011` | 1 | ×0.1 | Utility L1-L2 Voltage |
| `0x0012` | 1 | ×0.1 | Utility L2-L3 Voltage |
| `0x0013` | 1 | ×0.1 | Utility L3-L1 Voltage |
| `0x0014` | 1 | ×0.1 | Utility L1 Frequency |
| `0x0015` | 1 | ×0.1 | Utility L2 Frequency |
| `0x0016` | 1 | ×0.1 | Utility L3 Frequency |
| `0x0017` | 1 | ×0.1 | Generator L1 Current |
| `0x0018` | 1 | ×0.1 | Generator L2 Current |
| `0x0019` | 1 | ×0.1 | Generator L3 Current |
| `0x001A` | 1 | ×0.1 | L1 Power kW |
| `0x001B` | 1 | ×0.1 | L2 Power kW |
| `0x001C` | 1 | ×0.1 | L3 Power kW |
| `0x001D` | 1 | ×0.1 | Total Power kW |
| `0x001E` | 1 |  | Percentage Load |
| `0x001F` | 1 | ×0.1 | L1 Load kVA |
| `0x0020` | 1 | ×0.1 | L2 Load kVA |
| `0x0021` | 1 | ×0.1 | L3 Load kVA |
| `0x0022` | 1 | ×0.1 | Total Load kVA |
| `0x0023` | 1 | ×0.1 | L1 Load kVR Reactive |
| `0x0024` | 1 | ×0.1 | L2 Load kVR Reactive |
| `0x0025` | 1 | ×0.1 | L3 Load kVR Reactive |
| `0x0026` | 1 | ×0.1 | Total Load kVR Reactive |
| `0x0027` | 2 | ×0.1 | Cumulative Energy kWh |
| `0x0029` | 2 | ×0.1 | Cumulative Apparent Energy kVAh |
| `0x002B` | 2 | ×0.1 | Cumulative Reactive Energy kVARh |
| | | | *— gap 0x002D–0x0032: do not poll —* |
| `0x0033` | 1 | ×0.1 | Oil Pressure Bar |
| `0x0034` | 1 | ×0.1 | Coolant Temp, C |
| `0x0035` | 1 | ×0.1 | Fuel Level Percent |
| `0x0036` | 1 | ×0.1 | Fuel Volume, L |
| | | | *— gap 0x0037–0x0037: do not poll —* |
| `0x0038` | 1 | ×0.1 | Battery Voltage |
| `0x0039` | 1 |  | Engine Speed |
| `0x003A` | 1 |  | Number of Starts |
| `0x003B` | 1 |  | Number of Trips |
| `0x003C` | 1 |  | Engine Run Time - Hours |
| `0x003D` | 1 |  | Engine Run Time - Minutes |
| | | | *— gap 0x003E–0x003F: do not poll —* |
| `0x0040` | 1 |  | Alarm Register 1 |
| `0x0041` | 1 |  | Alarm Register 2 |
| `0x0042` | 1 |  | Alarm Register 3 |
| `0x0043` | 1 |  | Alarm Register 4 |
| `0x0044` | 1 |  | Alarm Register 5 |
| `0x0045` | 1 |  | Alarm Register 6 |
| `0x0046` | 1 |  | Alarm Register 7 |
| `0x0047` | 1 |  | Alarm Register 8 |
| `0x0048` | 1 |  | Alarm Register 9 |
| `0x0049` | 1 |  | Alarm Register 10 |
| `0x004A` | 1 |  | Alarm Register 11 |
| `0x004B` | 1 |  | Alarm Register 12 |
| `0x004C` | 1 |  | Alarm Register 13 |
| `0x004D` | 1 |  | Alarm Register 14 |
| `0x004E` | 1 |  | Alarm Register 15 |
| `0x004F` | 1 |  | Status Register |
| `0x0050` | 1 |  | Time - Minutes |
| `0x0051` | 1 |  | Time - Hours |
| `0x0052` | 1 |  | Date - Month / Day |
| `0x0053` | 1 |  | Date - Year |
| `0x0054` | 1 |  | Nominal kW |
| `0x0055` | 1 |  | Controller Firmware |
| `0x0056` | 1 |  | Unknown Value |
| | | | *— gap 0x0057–0x00B4: do not poll —* |
| `0x00B5` | 1 |  | Controller Model  **(timeout risk — excluded)** |

## Alarm conditions (51 decoded)

Generated into `packages/gc1032-alarms.yaml` by `tools/gen_alarms.py`. Asserted when
`(raw & mask) == value` — which for the active-low nibbles means the nibble is zero.

| Reg | Mask | Asserted when | Condition |
| --- | --- | --- | --- |
| `0x0040` | `0xF000` | `== 0x0000` | Low Oil Pressure |
| `0x0040` | `0x0F00` | `== 0x0000` | High Coolant Temperature |
| `0x0040` | `0x00F0` | `== 0x0000` | Low Fuel Level |
| `0x0040` | `0x000F` | `== 0x0000` | Water Level Switch |
| `0x0041` | `0xF000` | `== 0x0000` | Engine Under Speed |
| `0x0041` | `0x0F00` | `== 0x0000` | Engine Over Speed |
| `0x0041` | `0x00F0` | `== 0x0000` | Engine Failed to Start |
| `0x0041` | `0x000F` | `== 0x0000` | Engine Failed to Stop |
| `0x0042` | `0x00F0` | `== 0x0000` | Generator Low Frequency |
| `0x0042` | `0x000F` | `== 0x0000` | Generator High Frequency |
| `0x0043` | `0xF000` | `== 0x0000` | Generator High Current |
| `0x0043` | `0x0F00` | `== 0x0000` | Generator Overload |
| `0x0043` | `0x00F0` | `== 0x0000` | Unbalanced Load |
| `0x0043` | `0x000F` | `== 0x0000` | Emergency Stop |
| `0x0044` | `0x0F00` | `== 0x0000` | Maintenance Required |
| `0x0045` | `0xF000` | `== 0x0000` | Battery Low Voltage |
| `0x0045` | `0x0F00` | `== 0x0000` | Battery High Voltage |
| `0x0045` | `0x00F0` | `== 0x0000` | Temperature Circuit Open |
| `0x0046` | `0xF000` | `== 0x0000` | Fuel Theft |
| `0x0046` | `0x0F00` | `== 0x0000` | Magnetic Pick Up Fault |
| `0x0046` | `0x00F0` | `== 0x0000` | Oil Pressure Open Circuit |
| `0x0046` | `0x000F` | `== 0x0000` | Auxiliary Input I |
| `0x0047` | `0xF000` | `== 0x0000` | Auxiliary Input A |
| `0x0047` | `0x0F00` | `== 0x0000` | Auxiliary Input B |
| `0x0047` | `0x00F0` | `== 0x0000` | Auxiliary Input C |
| `0x0047` | `0x000F` | `== 0x0000` | Auxiliary Input D |
| `0x0048` | `0xF000` | `== 0x0000` | Auxiliary Input E |
| `0x0048` | `0x0F00` | `== 0x0000` | Auxiliary Input F |
| `0x0048` | `0x00F0` | `== 0x0000` | Auxiliary Input G |
| `0x0048` | `0x000F` | `== 0x0000` | Auxiliary Input H |
| `0x0049` | `0xF000` | `== 0x0000` | Gen L1 Phase Low Voltage |
| `0x0049` | `0x0F00` | `== 0x0000` | Gen L1 Phase High Voltage |
| `0x0049` | `0x00F0` | `== 0x0000` | Gen L2 Phase Low Voltage |
| `0x0049` | `0x000F` | `== 0x0000` | Gen L2 Phase High Voltage |
| `0x004A` | `0xF000` | `== 0x0000` | Gen L3 Phase Low Voltage |
| `0x004A` | `0x0F00` | `== 0x0000` | Gen L3 Phase High Voltage |
| `0x004A` | `0x00F0` | `== 0x0000` | DG Phase Rotation |
| `0x004A` | `0x000F` | `== 0x0000` | Mains Phase Rotation |
| `0x004B` | `0xF000` | `== 0x0000` | Fuel Cap Open Circuit |
| `0x004B` | `0x00F0` | `== 0x0000` | Extended Over Load Trip |
| `0x004B` | `0x000F` | `== 0x0000` | High Oil Pressure Detected |
| `0x004C` | `0xF000` | `== 0x0000` | Alternator Input Lost |
| `0x004C` | `0x0F00` | `== 0x0000` | High Voltage Warning (Ph-Ph) |
| `0x004C` | `0x00F0` | `== 0x0000` | High Voltage Warning 1 (Ph-Ph) |
| `0x004C` | `0x000F` | `== 0x0000` | High Voltage Warning 2 (Ph-Ph) |
| `0x004D` | `0xF000` | `== 0x0000` | Low Voltage Failure 1 (Ph-Ph) |
| `0x004D` | `0x0F00` | `== 0x0000` | Low Voltage Failure 2 (Ph-Ph) |
| `0x004F` | `0x0020` | `== 0x0020` | Generator Failed to Start |
| `0x004F` | `0x0001` | `== 0x0001` | General Notification |
| `0x004F` | `0x0002` | `== 0x0002` | General Warning |
| `0x004F` | `0x0004` | `== 0x0004` | Electrical Trip |

`Maintenance Required` (0x0044) is typed `regex` rather than `bits` in genmon and its
decode is a guess — it ships `disabled_by_default: true`. Confirm it against the
controller's own display before enabling it.

## Registers the InfoHub never showed you

`alt_input_registers` in the vendored JSON lists ~30 more addresses that respond on
*some* controllers and time out on others, all labelled "Unknown". They are not polled
by this firmware. To find out which ones your unit answers — and which of those
actually carry moving data — use the bench probe:

```bash
python3 tools/gc1032_probe.py sweep --port /dev/cu.usbserial-XXXXXXXX --baud 19200 --parity N
```

Run it once at rest and once during an exercise cycle, then compare. Anything that
responds, is absent from the table above, and *changes* is a candidate. Add it as a
sensor with `force_new_range: true` so a slow or flaky register cannot take the rest
of the polling loop down with it.

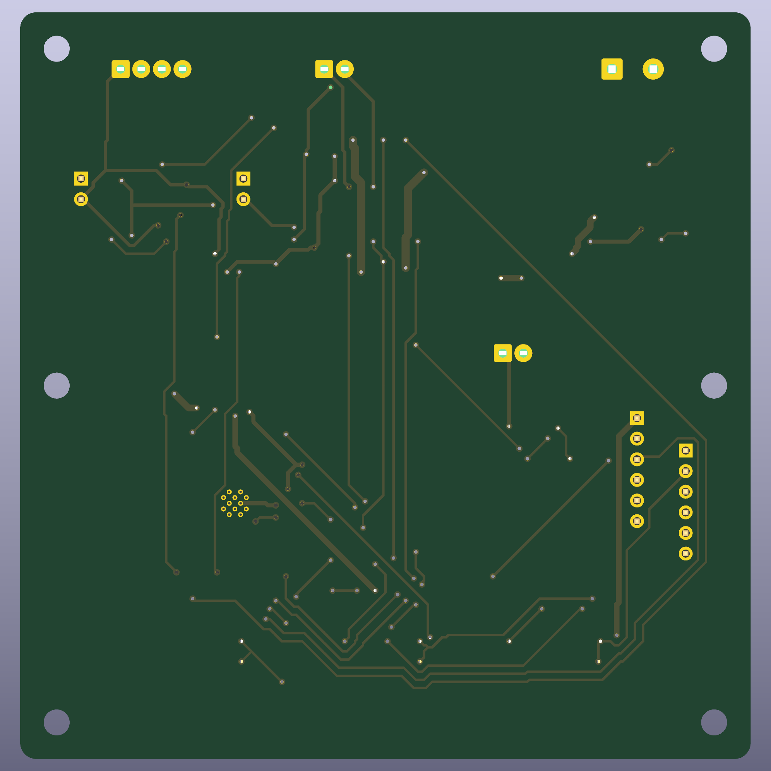
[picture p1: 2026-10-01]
hardware/pcb/preview/bottom.png

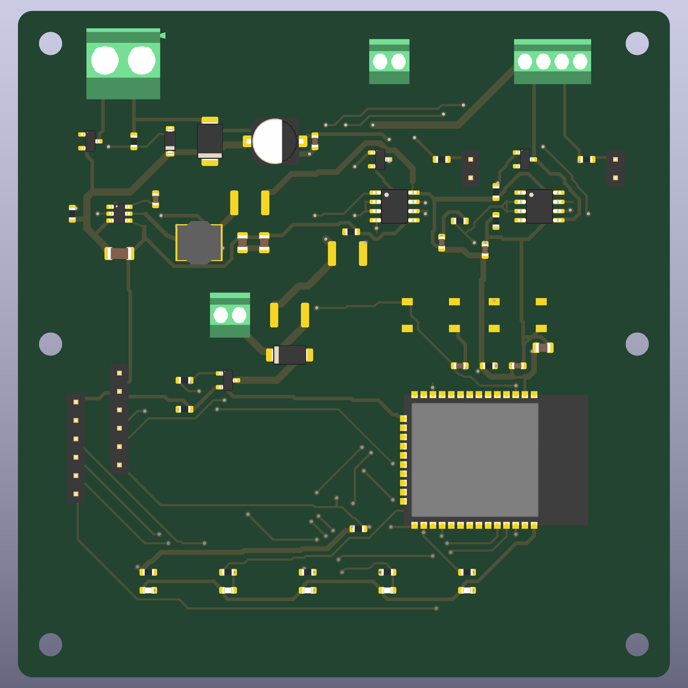
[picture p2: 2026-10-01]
hardware/pcb/preview/top.png

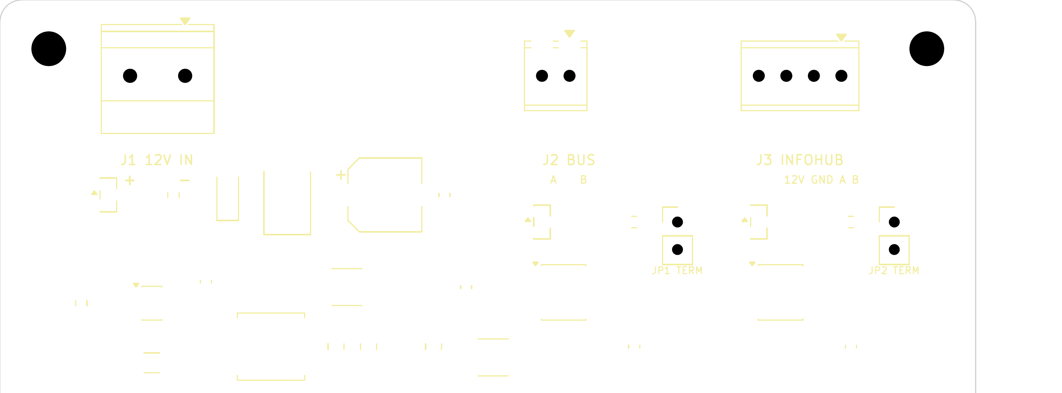
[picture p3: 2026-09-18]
hardware/pcb/preview/silk_top-1.png

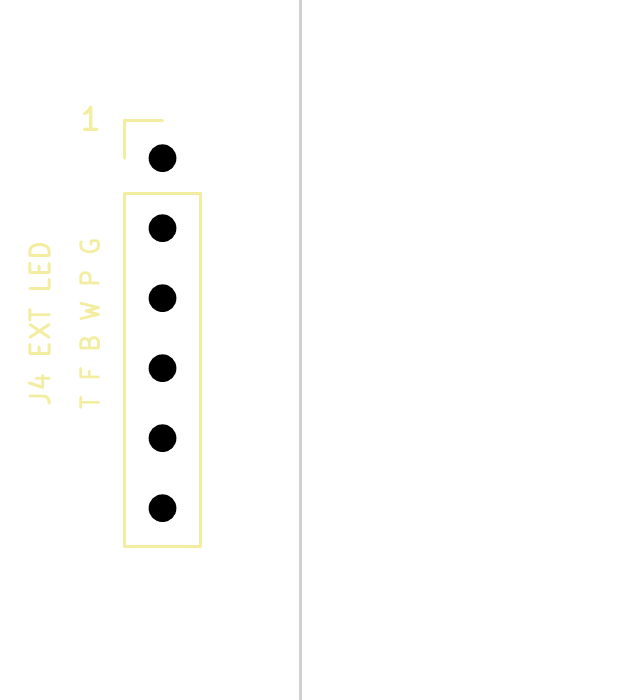
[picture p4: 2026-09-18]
hardware/pcb/preview/j4crop-1.png

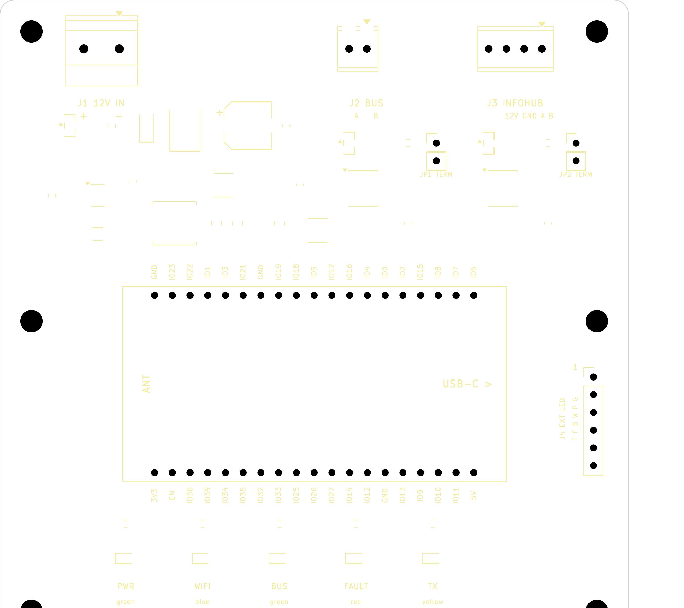
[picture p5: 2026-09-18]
hardware/pcb/preview/silk_front-1.png

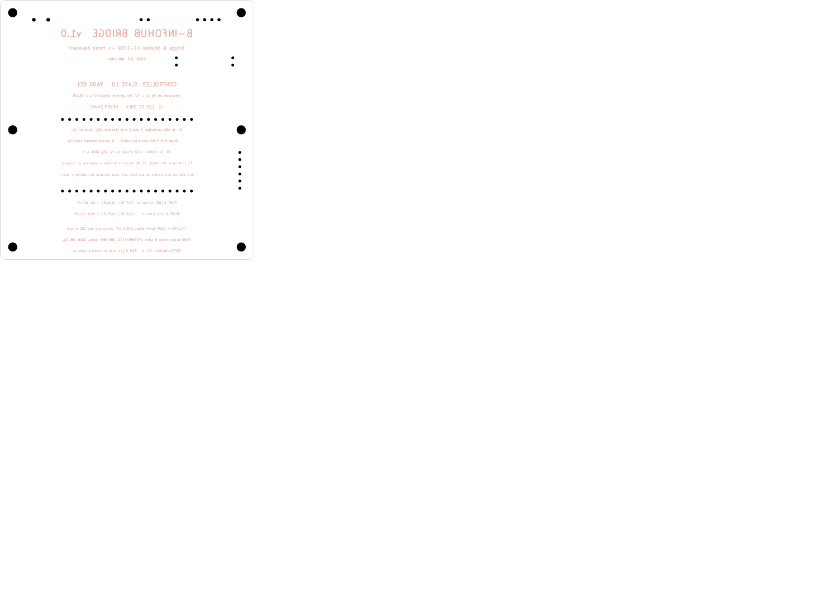
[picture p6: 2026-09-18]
hardware/pcb/preview/silk_back-1.png

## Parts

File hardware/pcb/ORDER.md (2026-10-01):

# Ordering — B-Infohub Bridge v1.1

## 1. PCB + assembly (JLCPCB)

Upload as-is:

| File | Where it goes |
| --- | --- |
| `binfohub_bridge_jlc.zip` | Gerber upload |
| `bom_jlc.csv` | Assembly → BOM |
| `cpl_jlc.csv` | Assembly → pick-and-place (CPL) |

Board options: **90 × 92 mm, 2 layers, 1.6 mm FR4, 1 oz copper, HASL or ENIG,
green/any mask.** Nothing here needs impedance control, castellation, or special
finish. Same outline and holes as rev 1.0 — it fits the rev 1.0 enclosure.

Assembly: **top side only.** Every SMT part is on F.Cu, **including the ESP32
module** (rev 1.1 solders an ESP32-WROOM-32E; there are no socket rows any more).
The through-hole parts (J1–J6, JP1, JP2) are flagged in the BOM as
`JLC THT (economic, hand-solder fee)` — include them if you want JLC to fit them,
or drop those rows and hand-solder.

**Assembly tier: Standard, not Economic.** The ESP32-WROOM-32E-**H4** (C3013935,
the 105 °C grade this board needs) is only offered on JLC's Standard PCBA. Pick
Standard when the quote asks; Economic will reject the part.

Stock was checked on 2026-10-01 for the parts new in rev 1.1 (module, AP63203,
AO3400A, SS14, TS-1187A, 1.1 A polyfuse, 680 Ω, 1 µF / 10 µF); re-check the rest
in JLC's BOM review before paying — rev 1.0's check is a month old. **C25804 (10 k,
×5) showed out of stock on LCSC's retail side on 2026-10-01**; JLC's assembly pool
is separate, but if the BOM review flags it, substitute any in-stock 0603 10 k ±1 %
basic part — there is nothing special about it.

## 2. Loose parts — NOT on the PCB BOM

JLC will not place these; order them as normal LCSC line items, or use what you have.

| Qty | Part | LCSC | Note |
| --- | --- | --- | --- |
| 2–4 | 2.54 mm jumper shunt (black, capped) | **C100114** | JP1 / JP2 termination. **Ship the board with these OFF** — see the termination section in README.md. Buy spares; they cost nothing and vanish. |
| 1 | 3.3 V USB-serial adapter (CP2102 / CH340, with a 3.3 V logic setting) | any | For the one first flash through J6. Wire GND, TX→RX, RX→TX; hold BOOT, tap RESET, `esphome run`. Do not power the board from it — feed 12 V on J1. |

Optional, depending on how you build it:

| Qty | Part | Note |
| --- | --- | --- |
| 1 | **ESP32-WROOM-32UE-N4** (C2934568) in place of the -32E | Remote antenna. Same pads; swap the U1 line in the BOM. |
| 1 | U.FL → SMA bulkhead pigtail + 2.4 GHz antenna | With the -32UE. The U.FL is on the module's top face, at its antenna end (board +x). |
| 1 | 12 V 2-wire fan, ≤ 0.5 A (40–60 mm) | J5. Only if shading/venting the box is not enough; see *Heat* in README.md. Enable `packages/fan.yaml` in the firmware. |
| 5 | 3 mm clear acrylic rod, 21 mm | Light pipes — see the enclosure README |
| 12 | M3 × 5 × 4.6 brass heat-set inserts | Enclosure |
| 3 | PG7 cable gland | Enclosure |
| 2 | M12 × 1.5 Gore-type vent | Enclosure — one low, **one high**, so the box convects. Rev 1.0 had one, low, and still reached 188 °F at the die. |

## 3. Before you press order

- **Terminal-block orientation.** `circuit.py` rotates every screw terminal 180° so
  the wire openings face the board edge. This is the exact issue JLC's DFM review
  flagged on the b-hydro board. Check the 3D render they generate: **J1/J2/J3 wire
  openings should face outward, toward the top edge; J5 (fan, interior) faces the
  same way.**
- **J2 is 2-position, J3 is 4-position, J5 is 2-position.** If the render shows
  anything else, stop.
- **U1 orientation — new in rev 1.1, not yet verified in JLC's viewer. A miss is a
  dead board (every pad on the wrong net).** In the placement preview: **pin 1 at
  board (71.26, 53.25)** and the antenna pointing at the right-hand edge (+x), over
  the bare strip, where the front silk says `ANT >`. If the render shows otherwise,
  fix the `ESPW` entry in `ROT_FIX` (tools/gen_bom.py) and re-export the CPL. Same
  pass for **D10** (SS14 cathode band toward F3 / the +12 V side) and the two
  **TS-1187A** switches (180° is harmless, 90° is not — their pads are not square).
- **J4/J6/JP1/JP2 headers** now get the +90° that b-hydro's headers needed; it has
  not been seen in the viewer for these footprints. Check, or hand-solder them.
- The `lib_footprint_mismatch` DRC warnings on J2/J3/J5 are expected: the locating
  pegs are deliberately stripped because the KF128 parts we buy do not have them.

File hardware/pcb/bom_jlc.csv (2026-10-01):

Comment | Designator | Footprint | LCSC Part # | Qty | Assembly | Note | Description
100uF 25V | C1 | CP_Elec_6.3x7.7 | C3338 | 1 | JLC SMT |  | 12 V bulk: holds the rail through the crank dip (11.4 V measured 2026-08-31)
100nF 50V | C2,C4,C8,C9,C10 | C_0603_1608Metric | C14663 | 5 | JLC SMT |  | 3.3 V HF decoupling, 4.5 mm from the VDD pad
10uF 50V | C3 | C_1206_3216Metric | C13585 | 1 | JLC SMT |  | buck input cap, right at VIN. 50 V not 25 V: ceramics lose a lot of capacitance under DC bias, and this sits on a 14.6 V rail. (b-hydro used C89632; that part is down to single-digit stock at LCSC, so this board takes the basic-part equivalent.)
22uF 25V | C5,C6 | C_0805_2012Metric | C45783 | 2 | JLC SMT |  | buck output cap 1
10uF 25V | C7 | C_0805_2012Metric | C15850 | 1 | JLC SMT |  | 3.3 V bulk near the module VDD pad
1uF 50V | C11 | C_0603_1608Metric | C15849 | 1 | JLC SMT |  | EN reset RC (10k/1uF ~ 10 ms)
BZT52C10 | D1 | D_SOD-123 | C173431 | 1 | JLC SMT |  | 10 V zener gate-source: clamps Q1 Vgs within the AO3401A +-12 V limit
SMBJ16A | D2 | D_SMB | C353386 | 1 | JLC SMT |  | Input TVS. b-hydro skipped this on purpose (indoor). A generator pad is not indoor: the starter is a large inductive load. 16 V standoff clears the 14.6 V charging rail.
SM712 | D3,D4 | SOT-23 | C32677 | 2 | JLC SMT |  | PSM712 RS-485 TVS on the controller pair (asymmetric -7/+12 V, the RS-485 standard part)
GREEN | D5,D7 | LED_0603_1608Metric | C965804 | 2 | JLC SMT |  | GREEN LED -- Modbus online: the controller is answering. Sits under a light pipe in the lid; see enclosure docs.
BLUE | D6 | LED_0603_1608Metric | C965807 | 1 | JLC SMT |  | BLUE LED -- Wi-Fi associated. Sits under a light pipe in the lid; see enclosure docs.
RED | D8 | LED_0603_1608Metric | C2286 | 1 | JLC SMT |  | RED LED -- a generator fault is active. Sits under a light pipe in the lid; see enclosure docs.
YELLOW | D9 | LED_0603_1608Metric | C965803 | 1 | JLC SMT |  | YELLOW LED -- transmit: driven from DE, so it needs no GPIO and proves the bridge is actually talking. Sits under a light pipe in the lid; see enclosure docs.
SS14 | D10 | D_SMA | C2480 | 1 | JLC SMT |  | Flyback across the fan: cathode to +12 V, anode to the switched node
1.1A polyfuse | F1 | Fuse_1812_4532Metric | C883148 | 1 | JLC SMT |  | 1.1 A hold / 2.2 A trip on the 3.3 V rail, below the buck's 3.2 A limit
2A polyfuse 1812 | F2 | Fuse_1812_4532Metric | C2760293 | 1 | JLC SMT |  | SMD1812-200C-30V, 2 A hold / 4 A trip, 30 V: InfoHub supply, independent of F1
1.1A polyfuse 1812 33V | F3 | Fuse_1812_4532Metric | C142747 | 1 | JLC SMT |  | Littelfuse 1812L110/33MR: 1.1 A hold / 1.95 A trip, 33 V. Fan supply, independent of F1/F2
12V IN | J1 | TerminalBlock_Phoenix_MKDS-1,5-2-5.08_1x02_P5.08mm_Horizontal | C474881 | 1 | JLC THT (economic, hand-solder fee) |  | Screw terminal 5.08 2P: +12 V (harness red/grey) and GND (harness black)
TERM 120R | JP1,JP2 | PinHeader_1x02_P2.54mm_Vertical | C492401 | 2 | JLC THT (economic, hand-solder fee) |  | 120R termination jumper, controller side. LEAVE OPEN by default: 368 consecutive error-free block reads at 9600 8E1 on 2026-08-31 with an unterminated adapter, and at 104 us per bit reflections settle ~1000x faster than the sampling instant. Fit only if CRC errors appear.
BUS A B (FAN 12V) | J2,J5 | TerminalBlock_Phoenix_MPT-0,5-2-2.54_1x02_P2.54mm_Horizontal | C474920 | 2 | JLC THT (economic, hand-solder fee) |  | Screw terminal 2.54 2P to the ABC controller: A and B only. The harness ground arrives on J1 and is the same net, so a separate ground pin here would be redundant. Swap A/B if the bus stays silent.
IH 12V GND A B | J3 | TerminalBlock_Phoenix_MPT-0,5-4-2.54_1x04_P2.54mm_Horizontal | C474922 | 1 | JLC THT (economic, hand-solder fee) |  | Screw terminal 2.54 4P to the InfoHub: +12 V (fused by F2), GND, A, B
LED OUT (PROG) | J4,J6 | PinHeader_1x06_P2.54mm_Vertical | C492405 | 2 | JLC THT (economic, hand-solder fee) |  | Programming header: 3V3, GND, TX0, RX0, EN, IO0. First flash only; OTA after that.
10uH 2.5A | L1 | L_Bourns_SRN6045TA | C79272 | 1 | JLC SMT |  | SWPA6045S100MT shielded 6x6
AO3401A | Q1 | SOT-23 | C15127 | 1 | JLC SMT |  | P-MOSFET reverse-polarity protection, 4 A -- carries BOTH our load and the InfoHub passthrough
AO3400A | Q2 | SOT-23 | C20917 | 1 | JLC SMT |  | N-MOSFET low-side fan switch, 5.7 A, logic-level gate
4k7 | R1 | R_0603_1608Metric | C23162 | 1 | JLC SMT |  | Q1 gate pull-down; ~0.4 mA through D1 keeps the clamp in its characterised region
100k | R2 | R_0603_1608Metric | C25803 | 1 | JLC SMT |  | buck EN pull-up (always on)
120R | R3,R4 | R_0603_1608Metric | C22787 | 2 | JLC SMT |  | bus termination, controller side
100R | R5,R6,R7,R12 | R_0603_1608Metric | C22775 | 4 | JLC SMT |  | D5 series resistor, ~4 mA. Small value: blue/green Vf leaves little headroom on 3.3 V.
330R | R8,R9 | R_0603_1608Metric | C23138 | 2 | JLC SMT |  | D8 series resistor, ~4 mA.
680R | R10,R11 | R_0603_1608Metric | C23228 | 2 | JLC SMT |  | Fail-safe bias, InfoHub pair: pull-down on B. 680R covers an unterminated pair or a terminated far end; ~390R if both ends are terminated. Rev 1.1.
10k | R13,R14,R15,R16,R17 | R_0603_1608Metric | C25804 | 5 | JLC SMT |  | B_DE pull-down: port B transceiver in receive while the ESP is in reset or being flashed (see R16)
TS-1187A | SW1,SW2 | SW_TS-1187A | C318884 | 2 | JLC SMT |  | RESET: pulls EN low. XKB TS-1187A-B-A-B 5.1 mm tactile, JLC basic part
ESP32-WROOM-32E-H4 | U1 | ESP32-WROOM-32E_edge | C3013935 | 1 | JLC SMT |  | ESP32-WROOM-32E-H4: 4 MB, -40..+105 C grade (the plain -32E is 85 C, and this revision exists because the die reached 87 C). Soldered module, antenna toward the board edge. Standard PCBA only at JLC. ALTERNATE: ESP32-WROOM-32UE-N4 (C2934568, 85 C grade) -- identical pads, U.FL instead of the PCB antenna; fit with a U.FL-to-SMA bulkhead pigtail through the enclosure for a remote antenna. Rev 1.1.
AP63203WU-7 | U2 | TSOT-23-6 | C780769 | 1 | JLC SMT |  | Sync buck 3.8-32 V in, fixed 3.3 V 2 A, TSOT-23-6. Rev 1.1: was AP63205 (5 V).
SP3485EN | U3,U4 | SOIC-8_3.9x4.9mm_P1.27mm | C8963 | 2 | JLC SMT |  | 3.3 V half-duplex RS-485, controller side. RE and DE tied: one GPIO drives direction.

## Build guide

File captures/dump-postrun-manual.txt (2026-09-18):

REG     RAW         VALUE           NAME
------------------------------------------------------------------------
0x0000  0x8003      32771           Protocol Revision
0x0001  0x0         0.00            Generator L1 Voltage
0x0002  0x0         0.00            Generator L2 Voltage
0x0003  0xFFFF      6553.50         Generator L3 Voltage
0x0004  0x0         0.00            Generator L1-L2 Voltage
0x0005  0xFFFF      6553.50         Generator L2-L3 Voltage
0x0006  0xFFFF      6553.50         Generator L3-L1 Voltage
0x0007  0x0         0.00            Generator L1 Frequency
0x0008  0x0         0.00            Generator L2 Frequency
0x0009  0xFFFF      6553.50         Generator L3 Frequency
0x000A  0x0         0.00            L1 Power Factor
0x000B  0x0         0.00            L2 Power Factor
0x000C  0xFFFF      655.35          L3 Power Factor
0x000D  0x0         0.00            Average Power Factor
0x000E  0x49C       118.00          Utility L1 Voltage
0x000F  0x49C       118.00          Utility L2 Voltage
0x0010  0xFFFF      6553.50         Utility L3 Voltage
0x0011  0x942       237.00          Utility L1-L2 Voltage
0x0012  0xFFFF      6553.50         Utility L2-L3 Voltage
0x0013  0xFFFF      6553.50         Utility L3-L1 Voltage
0x0014  0x257       59.90           Utility L1 Frequency
0x0015  0x258       60.00           Utility L2 Frequency
0x0016  0xFFFF      6553.50         Utility L3 Frequency
0x0017  0x0         0.00            Generator L1 Current
0x0018  0x1         0.10            Generator L2 Current
0x0019  0xFFFF      6553.50         Generator L3 Current
0x001A  0x0         0.00            L1 Power kW
0x001B  0x0         0.00            L2 Power kW
0x001C  0x0         0.00            L3 Power kW
0x001D  0x0         0.00            Total Power kW
0x001E  0x0         0               Percentage Load
0x001F  0x0         0.00            L1 Load kVA
0x0020  0x0         0.00            L2 Load kVA
0x0021  0x0         0.00            L3 Load kVA
0x0022  0x0         0.00            Total Load kVA
0x0023  0x0         0.00            L1 Load kVR Reactive
0x0024  0x0         0.00            L2 Load kVR Reactive
0x0025  0xFFFF      6553.50         L3 Load kVR Reactive
0x0026  0x0         0.00            Total Load kVR Reactive
0x0027  0x51E       131.00          Cumulative Energy kWh
0x0029  0x56E       139.00          Cumulative Apparent Energy kVAh
0x002B  0x46        7.00            Cumulative Reactive Energy kVARh
0x0033  0xFFFF      6553.50         Oil Pressure Bar
0x0034  0x168       36.00           Coolant Temp, C
0x0035  0xFFFF      6553.50         Fuel Level Percent
0x0036  0xFFFF      6553.50         Fuel Volume, L
0x0038  0x85        13.30           Battery Voltage
0x0039  0x0         0               Engine Speed
0x003A  0x118       280             Number of Starts
0x003B  0x2         2               Number of Trips
0x003C  0x5C        92              Engine Run Time - Hours
0x003D  0x23        35              Engine Run Time - Minutes
0x0040  0x1100      4352            Alarm Register 1
0x0041  0x1111      4369            Alarm Register 2
0x0042  0xFF11      65297           Alarm Register 3
0x0043  0x1111      4369            Alarm Register 4
0x0044  0xF0F0      61680           Alarm Register 5
0x0045  0x111F      4383            Alarm Register 6
0x0046  0x100       256             Alarm Register 7
0x0047  0x11        17              Alarm Register 8
0x0048  0x1001      4097            Alarm Register 9
0x0049  0x1111      4369            Alarm Register 10
0x004A  0x0         0               Alarm Register 11
0x004B  0xF01       3841            Alarm Register 12
0x004C  0x1F11      7953            Alarm Register 13
0x004D  0x11FE      4606            Alarm Register 14
0x004E  0x1         1               Alarm Register 15
0x004F  0x6080      24704           Status Register
0x0050  0x1F00      7936            Time - Minutes
0x0051  0xFF10      65296           Time - Hours
0x0052  0x81F       2079            Date - Month / Day
0x0053  0x7EA       2026            Date - Year
0x0054  0x18FF      6399            Nominal kW
0x0055  0x4113      16659           Controller Firmware
0x0056  0x9EEC      40684           Unknown Value
0x00B5  skipped                     Controller Model  (known timeout risk)

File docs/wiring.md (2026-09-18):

# Wiring

## 0. Before anything else

- **Generator selector to OFF, then disconnect the battery.** A standby generator in
  AUTO will crank while your hands are in the cabinet — it does not care that you are
  in there. This is the only genuinely dangerous step in the project.
- **Disconnect the InfoHub from the RS-485 pair.** Modbus RTU allows exactly one
  master. Leaving it wired in means collisions, corrupt frames in both directions, and
  hours spent debugging a wiring problem you do not have.
- **Meter before you connect.** Every wire colour below is what the documentation and
  the genmon community report. Your harness is the authority, not this file.

## 1. Where the bus is

The InfoHub interface harness carries five wires, and it is the easiest tap point
because it is already routed out of the engine enclosure:

| Wire | Function |
| --- | --- |
| Red | +12 VDC |
| Grey | +12 VDC (may be switched or separately fused — meter both) |
| Black | Ground |
| Brown | RS-485 data |
| Yellow | RS-485 data |

Everything this project needs is in that one connector: power and the differential
pair. Pulling the InfoHub frees all of it.

**Which of brown/yellow is A and which is B is not documented.** Nobody knows without
trying. Connect one way, and if the bus stays silent, swap them. This costs ten
seconds and is the single most common reason a first attempt reads nothing — the same
rule as the AID port on the WaterFurnace bridges.

Bus settings: whatever the controller's **Module → Communication** menu reports.
Confirm `COMM MODE` is `MODBUS` and not `None`, and note the slave ID, baud and
parity. Several of these are dealer-locked (the password lives on the B&S Power
Portal), so you may be able to view but not change them. Viewing is all you need —
match your side to whatever it says. If you cannot get into the menu, `gc1032_probe.py
scan` finds the settings without touching the panel.

## 2. Bench probing with the FTDI USB-RS485 cable

This is the fastest way to find out what the controller will actually tell you, and it
needs no soldering and no ESP32.

### Which pins get the data wires — SETTLED BY BENCH TEST

This adapter exposes **T/R+, T/R-, RXD+, RXD- and GND**. It was bench-tested with
`tools/adapter_check.py` and the answer is not the obvious one:

- **No jumpers:** transmitted correctly, received *nothing*.
- **RXD+ tied to T/R+, RXD- tied to T/R-:** clean byte-for-byte echo of the frame.

That is **full-duplex RS-422 silicon**. Its driver is on T/R± and its receiver is on a
*separate* RXD± pair. Used as 2-wire RS-485 without the jumpers it talks and never
hears — which on a live bus is indistinguishable from a reversed pair, a dead
controller, or the InfoHub stealing the replies.

**Keep the jumpers. Final wiring:**

| Adapter | | Connect to |
| --- | --- | --- |
| **T/R+** *and* **RXD+** tied together | → | one harness data wire (bus A) |
| **T/R-** *and* **RXD-** tied together | → | the other harness data wire (bus B) |
| **GND** | → | harness black (ground) |

If the adapter also has a +5 V / VBUS lead, leave it disconnected and heat-shrink it.
It is an output from the USB bus, and the harness has +12 V on red and grey — bridging
them back-feeds 12 V into the Mac's USB port.

The only unknown left at the generator is which harness data wire is A. If `scan`
finds nothing, swap the two joined pairs and run it once more. Nothing here can damage
the controller or the adapter — a reversed differential pair simply decodes nothing.

Re-verify at any time, with nothing connected to the generator:

```bash
python3 tools/adapter_check.py --port /dev/cu.usbserial-A94C31KL --jumpered
```

### Use /dev/cu.*, not /dev/tty.*

macOS exposes every serial device twice. `/dev/tty.*` is the *incoming* (dial-in) node
and blocks on open until it sees carrier detect, which a USB-RS485 adapter never
asserts — so it can hang instead of failing. `/dev/cu.*` ("callout") is the outbound
node and is the correct one here. Same device, same adapter, different open semantics.

Verified working on this machine: **`/dev/cu.usbserial-A94C31KL`**.

### Then

```bash
pip install pyserial
ls /dev/cu.usbserial-*                       # find the port
python3 tools/gc1032_probe.py scan  --port /dev/cu.usbserial-XXXXXXXX
python3 tools/gc1032_probe.py dump  --port /dev/cu.usbserial-XXXXXXXX --baud 19200 --parity N
python3 tools/gc1032_probe.py sweep --port /dev/cu.usbserial-XXXXXXXX --baud 19200 --parity N
```

`scan` brute-forces baud, parity and slave id. `dump` reads every documented register
once. `sweep` probes the whole low register space twice and reports which
**undocumented** registers respond and which ones moved — that is where data the
InfoHub never showed you lives. Run `sweep` again during an exercise cycle; most of
the interesting registers only change while the engine is turning.

The probe tool never writes. There is no write function in it at all.

## 3. Permanent install — ESP32 + MAX485

Same hardware pattern as the WaterFurnace bridges: ESP32-DevKitC 38-pin
(ESP32-WROOM-32D) plus a MAX485 module **with exposed DE/RE pins**. Auto-direction
modules are unreliable at Modbus timing — if that is what you have, replace it rather
than fight it.

| From | To | Notes |
| --- | --- | --- |
| MAX485 DI | ESP **GPIO17** | ESP transmits into the module |
| MAX485 RO | ESP **GPIO16** | module output to ESP (3.3 V logic, since VCC is 3.3 V) |
| MAX485 DE **and** RE (bridge them) | ESP **GPIO4** | HIGH to transmit, LOW to receive |
| MAX485 VCC | ESP **3V3** | clone modules run fine at 3.3 V on a short stub |
| MAX485 GND | ESP GND | |
| MAX485 A | harness data wire 1 | swap with B if the bus never connects |
| MAX485 B | harness data wire 2 | |
| Buck 5 V out | ESP **VIN** | see below — never feed VIN from anything unregulated |
| Buck ground | ESP GND | common with harness black |

These pins match `genset-gc1032.yaml`; change them there, not here.

**Termination.** With the InfoHub removed you are one of two nodes, so the module's
onboard 120 Ω is correct — leave it. If you ever put a third device back on the pair,
termination belongs at the two physical ends only and this module's resistor must come
off (solder jumper on most clones; some are hard-wired and need the resistor lifted).

## 4. The 12 V power front end

The harness gives you +12 V, but treat it as automotive DC, not a clean rail:

- Resting ~12.6–13.2 V; ~13.5–14.6 V while the charger is on.
- **Cranking drops it to 8–9 V for a second or two on every start.** A converter with
  a 9 V minimum input browns out the ESP32 at exactly the moment you most want data.
- Load dump when the starter disengages — an inductive spike above 14 V.

So, in order from the harness:

```
harness +12 V ──[ 1 A fuse ]──[ reverse-polarity Schottky or P-FET ]──┬──[ TVS to GND ]
                                                                      │
                                                          [ bulk cap, 220–470 µF ]
                                                                      │
                                                   [ wide-input 5 V DC-DC ] ── ESP32 VIN
harness ground ───────────────────────────────────────────────────────┴──────── ESP32 GND
```

| Part | Spec | Why |
| --- | --- | --- |
| DC-DC | **Recom R-78E5.0-1.0** (7–28 V in, 5 V @ 1 A) or any automotive 6–36 V unit | Wide input range is the whole point — it rides through cranking |
| Fuse | 1 A inline | |
| TVS | SMBJ16A or 1.5KE18A across the input | Clamps the load dump |
| Reverse protection | Schottky or P-FET | |
| Bulk cap | 220–470 µF | Holds the rail up through the crank dip |

Do **not** use a bare LM2596 module. They have no transient protection and the common
clones are marginal on both input range and noise.

Size for 1 A — Wi-Fi TX peaks pull 300–500 mA.

## 5. Grounding: pick one lane and stay in it

Powering from the generator battery means the ESP32's ground **is** the generator's
ground. That is fine, and it is why a non-isolated MAX485 is acceptable here — but
only because there is no second ground reference:

- **This build: battery power + Wi-Fi only.** One ground reference. Nothing to fight.
- **Alternative: PoE from the house + isolated RS-485 (ADM2582E).** The isolator breaks
  the loop.

What you must never do is power from the generator battery **and** run Ethernet back
to the house with a non-isolated transceiver. That puts the full house-to-pad ground
potential difference across the board.

Mount in a poly NEMA 4X enclosure **outside** the engine enclosure. Under-hood ambient
plus vibration kills a dev board faster than anything electrical will.

---

## InfoHub passthrough (PCB rev 1.0, port B)

Enabled by `packages/passthrough.yaml` and the **Feature: InfoHub Passthrough**
switch. Off by default.

### Why it is not optional to get this right

Modbus RTU permits exactly one master. The InfoHub is a master. So is this
bridge. Wire both to the generator's RS-485 pair and they transmit over each
other — corrupt frames in both directions, and an InfoHub reporting comm faults
to your dealer.

The board avoids that in hardware, with two transceivers:

| | Transceiver | ESP32 pins | Role |
|---|---|---|---|
| Port A | U3 | IO17 TX, IO16 RX, IO4 DE/RE | **master** — talks to the generator |
| Port B | U4 | IO22 TX, IO23 RX, IO21 DE/RE | **slave** — answers the InfoHub |

The InfoHub is no longer on the generator's bus at all. It talks to *us*, and
we answer at the same slave address from the values we just read. It cannot
tell the difference.

### Wiring

```
  generator RS-485  ──────►  J3 (A/B)   port A   sole master
  generator 12 V    ──────►  J1 (+/−)

  J2 (+/−)          ──────►  InfoHub 12 V        passthrough power
  J3 (A/B, IH pair) ──────►  InfoHub RS-485      port B
```

Never leave the InfoHub connected to the generator's own RS-485 pair once this
bridge is installed. That is the two-master case, and it is the one failure
mode this whole arrangement exists to prevent.

### What is served

All 84 registers across `0x0000`–`0x0056`, reconstructed from the scaled sensor
values by inverting each filter's `multiply`. Reconstruction rather than a
second raw read of the same addresses: a duplicate read would double traffic on
a 9600 baud bus the field notes already warn against saturating.

The round trip is exact for every 16-bit register — verified across all 65536
values at each scale in use (0.1, 0.01, 1/256, 1.0).

The three **32-bit** counters at `0x0027`, `0x0029` and `0x002B` are a special
case. An ESPHome sensor state is a float32 with 24 bits of mantissa, so above
~16.7 million it cannot hold a 32-bit counter exactly — 98% of values come back
altered. Those three are therefore captured as raw words from the response
bytes in `gc1032-power.yaml`, before any float is involved, and served from
there.

A register never read, or one the controller reported as `0xFFFF` ("sensor not
present"), is served as `0xFFFF` — exactly what the InfoHub would have seen
from the controller itself.

### What is NOT served: writes

**The InfoHub can no longer command the generator through this bridge.** Remote
start/stop from the Briggs app stops working; monitoring and cloud reporting
continue.

This is deliberate. Proxying writes would mean this bridge cranking an engine on
behalf of a remote request it cannot authenticate, using the control path that
was explicitly removed from this build. If you need remote start, wire the
InfoHub directly to the generator and do not run this bridge — you cannot have
both on one pair.

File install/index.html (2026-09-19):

# Install B-Infohub

Flash the generator bridge straight from this page. No toolchain, no command line.

You need Chrome or Edge on a desktop. Flashing uses Web Serial, which Safari and Firefox do not implement, and which mobile browsers do not expose. This is a browser limitation, not a choice — there is no way around it other than using a supported browser once.

1. Connect the bridge to your computer with a data USB cable. Charge-only cables are the single most common reason the button below finds nothing — they carry power but no data lines, so the board appears dead to the browser while its power LED is lit.
2. Click Connect and pick the serial port that appears.
3. Wait for the flash to finish, then follow the Wi-Fi prompt in the same dialog.

## After flashing

The bridge ships with no Wi-Fi network compiled in, deliberately — it is configured once, on the device, and the credentials survive future updates. Three ways in, and the installer above offers the first:

1. In this page — the install dialog asks for Wi-Fi when flashing finishes.
2. Bluetooth — the Home Assistant mobile app finds it and offers to set it up.
3. Its own hotspot — join b-infohub Setup and a captive portal opens.

Then add it to Home Assistant with the EnergyTrak integration (https://github.com/brentb2529/ha-energytrak). It is discovered automatically on the same subnet; on a routed or VLAN'd network, add it by IP instead.

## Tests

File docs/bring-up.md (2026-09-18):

# Bring-up and bench testing

Order matters here. Each step proves one thing, so that when something fails
you know which thing.

## 0. Before the first flash

```sh
cd ~/Documents/GitHub/B-Infohub
```

**Nothing in `secrets.yaml` blocks a first flash.** No network is compiled in;
the bridge onboards on first boot (step 1 below). The device-identity secrets —
`api_encryption_key`, `ota_password`, `ap_password`, `web_password` — are already
generated and unique to this board.

| | |
|---|---|
| `wifi_ssid`, `wifi_password` | optional — only if you pre-seed a network |
| `mqtt_broker`, `mqtt_username`, `mqtt_password` | optional — only if you turn MQTT on |

MQTT ships **off**. Home Assistant reaches the bridge over the native API, so
MQTT is an extra for Grafana. Set the broker, then flip *Feature: MQTT*.

### The first flash must be over USB

Not a preference — `partitions.csv` changes the partition table, and a partition
table cannot move itself over the air. Every update after this one is OTA.

```sh
.venv/bin/esphome run genset-gc1032.yaml
```

## 1. Onboard it to your network

Three routes, all live at once. Credentials land in NVS and survive re-flashing,
so this is a one-time step.

| | how | when it is the right one |
|---|---|---|
| **USB serial** | keep the cable in after flashing; `esphome run` offers to configure Wi-Fi, or use improv-wifi.com in Chrome | on the bench — the only route available before the board leaves it |
| **Bluetooth** | Home Assistant companion app, or improv-wifi.com | at the generator pad, where you do not want a laptop |
| **Setup Wi-Fi** | join `b-infohub Setup` (password `ap_password`); a config page opens by itself | no BLE, no cable |

The WIFI LED **blinks** while the setup AP is up and goes **solid** once
associated. Blinking-versus-dark is the distinction that matters: "needs
configuring" must not look like "radio is dead".

The AP also returns if a provisioned network is unreachable for a minute, so a
router swap does not mean a trip up a ladder.

Home Assistant should then discover the bridge by itself — it advertises
`project_name: bbensten.b_infohub` over mDNS. Paste `api_encryption_key` once.

## 2. Prove the firmware without the generator

`tools/gc1032_sim.py` replays `captures/run-2026-08-31.csv` — 368 frames at
1 Hz covering a **complete cycle**: 13 s at rest, 7 s cranking, 320 s running,
28 s stopping. Better than the real generator for this: repeatable, costs no
fuel, and replays at 20× on a bench.

Wire the FTDI cable to **port A** (J3, the generator pair) and run:

```sh
.venv/bin/python tools/gc1032_sim.py serve --port /dev/tty.usbserial-XXXX --loop
```

The simulator is deliberately as unhelpful as the real controller — FC03 gets
silence rather than an error, `0xFFFF` is replayed verbatim, and reads past
`0x0056` get an illegal-address exception. Firmware that quietly depends on a
polite error passes against a nicer simulator and fails in the field.

Protocol behaviour is covered by `tools/test_sim.py`, which needs no hardware:

```sh
.venv/bin/python tools/test_sim.py
```

**What to look for:** the BUS LED goes solid, and in Home Assistant the engine
state walks *at rest → cranking → running → stopping* while voltages, currents
and power move. 26% of the captured cells are `0xFFFF`, so the "sensor not
present" filters get properly exercised — those entities should read *unknown*,
not zero.

## 3. Prove the failover

This is the failure the whole design is built around, and it is worth seeing
with your own eyes:

```sh
.venv/bin/python tools/gc1032_sim.py serve --port ... --loop --kill-bus
```

The link stays physically up; the device just stops answering. Watch:

| | expected |
|---|---|
| `Bus Healthy` | goes **false** after 3 missed polls (~30 s) |
| `Bus Age` | climbs |
| BUS LED | goes **dark** |
| `telemetry_source` in HA | flips to **cloud** |

A bridge whose RS-485 has died stays online and keeps serving its last good
readings, which look exactly like a healthy idle generator. If `telemetry_source`
does not flip, the failover is broken — and it will be silent in service.

## 4. Prove the passthrough

Turn on *Feature: InfoHub Passthrough*, keep `serve` driving port A, and put a
second adapter on **port B** (the InfoHub pair):

```sh
.venv/bin/python tools/gc1032_sim.py verify --port /dev/tty.usbserial-YYYY
```

`verify` polls the proxy and diffs **every register** against the capture. It
exits non-zero on any mismatch, so it is the end-to-end check that the inverse
scaling reconstructs raw words correctly — including the three 32-bit counters
at `0x0027`/`0x0029`/`0x002B`, which cannot round-trip through a float32 and are
captured raw for exactly this reason.

Expect `all 87 registers match`.

## 5. When the PCB arrives — the deferred tests

Everything below needs an RS-485 transceiver, which is why it was deferred: on
a bare ESP32 it means wiring a MAX485 by hand, and rev 1.0 has SP3485s on
board. Do it in this order — each step is only meaningful if the previous one
passed.

**a. Flash the assembled board over USB.** Mandatory, not preference: the
partition table changed (`backlog` region), and a table cannot relocate the
image running from it.

**b. Bench replay, before the generator.** Wire the FTDI cable to J3 and let
the Mac play the controller:

```sh
.venv/bin/python tools/gc1032_sim.py serve --port /dev/cu.usbserial-XXXX --loop
```

Expect `Modbus device=10 set online`, `bus_healthy` true, the BUS LED solid,
and roughly 100 local-only entities appearing in Home Assistant. Those entities
have never been created against real data.

**c. Failover.** Re-run with `--kill-bus`. `bus_healthy` must go false within
~30 s and `telemetry_source` must stop claiming local. A bridge that keeps
serving frozen values is the failure this whole design exists to prevent.

**d. The snapshot ring.** Stop Home Assistant while the simulator runs. The
bridge should buffer a 12-value snapshot every 60 s; restart HA and confirm the
drain replays them. UNTESTED with real values — only synthetic ones so far.

**e. The passthrough proxy.** Enable *Feature: InfoHub Passthrough*, put a
second adapter on port B, and run:

```sh
.venv/bin/python tools/gc1032_sim.py verify --port /dev/cu.usbserial-YYYY
```

It diffs every register against the capture and exits non-zero on any
mismatch. Wholly untested — including the inverse scaling that reconstructs raw
words from float sensor states.

## 6. Only then, the generator

Read `docs/wiring.md` first, especially the passthrough section.

> **Never leave the InfoHub connected to the generator's own RS-485 pair once
> this bridge is installed.** Modbus RTU permits one master. That is the two-
> master case, and it is what this whole arrangement exists to prevent.

## Reading the lights

| | solid | blinking | off |
|---|---|---|---|
| **WIFI** | associated | setup portal up — join `b-infohub Setup` | radio down |
| **BUS** | controller answering | passthrough serving an InfoHub | **nothing heard** |
| **FAULT** | generator reporting a fault | **safe mode** — push firmware | no fault |
| **PWR** | 5 V rail alive (hard-wired, cannot lie) | | buck is dead |
| **TX** | | flashes on every transmission (wired to DE, no code) | not talking |

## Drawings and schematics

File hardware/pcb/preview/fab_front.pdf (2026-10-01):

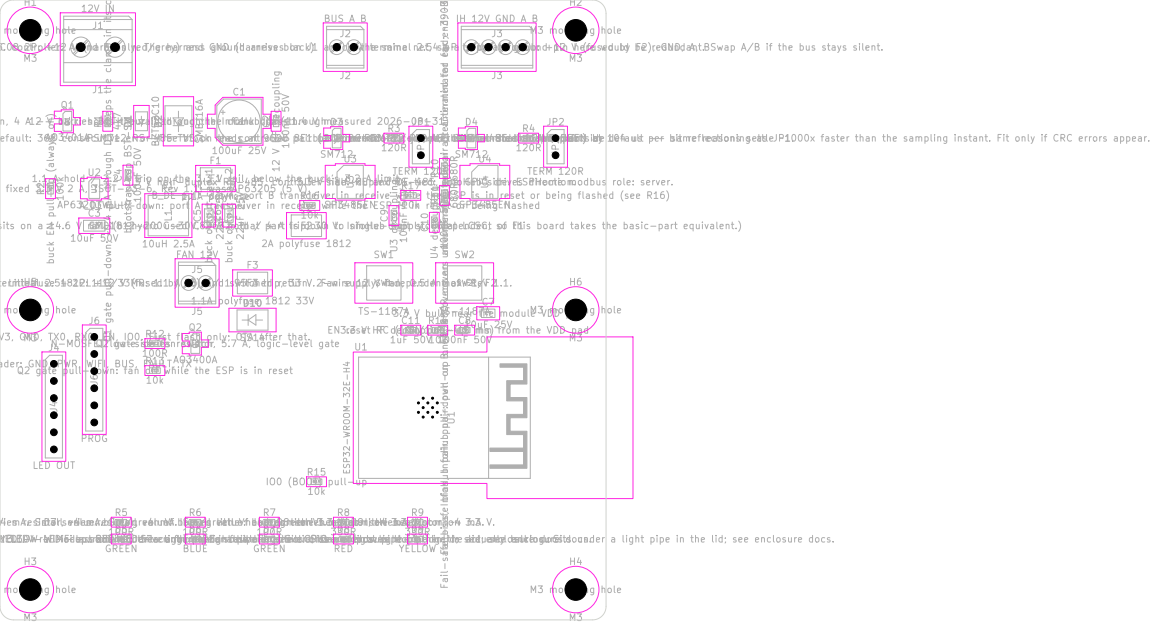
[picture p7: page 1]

D7 series resistor, ~4 mA. Small value: blue/green Vf leaves little headroom on 3.3 V. R7 D7 GREEN

D8 series resistor, ~4 mA. R8 D8 RED

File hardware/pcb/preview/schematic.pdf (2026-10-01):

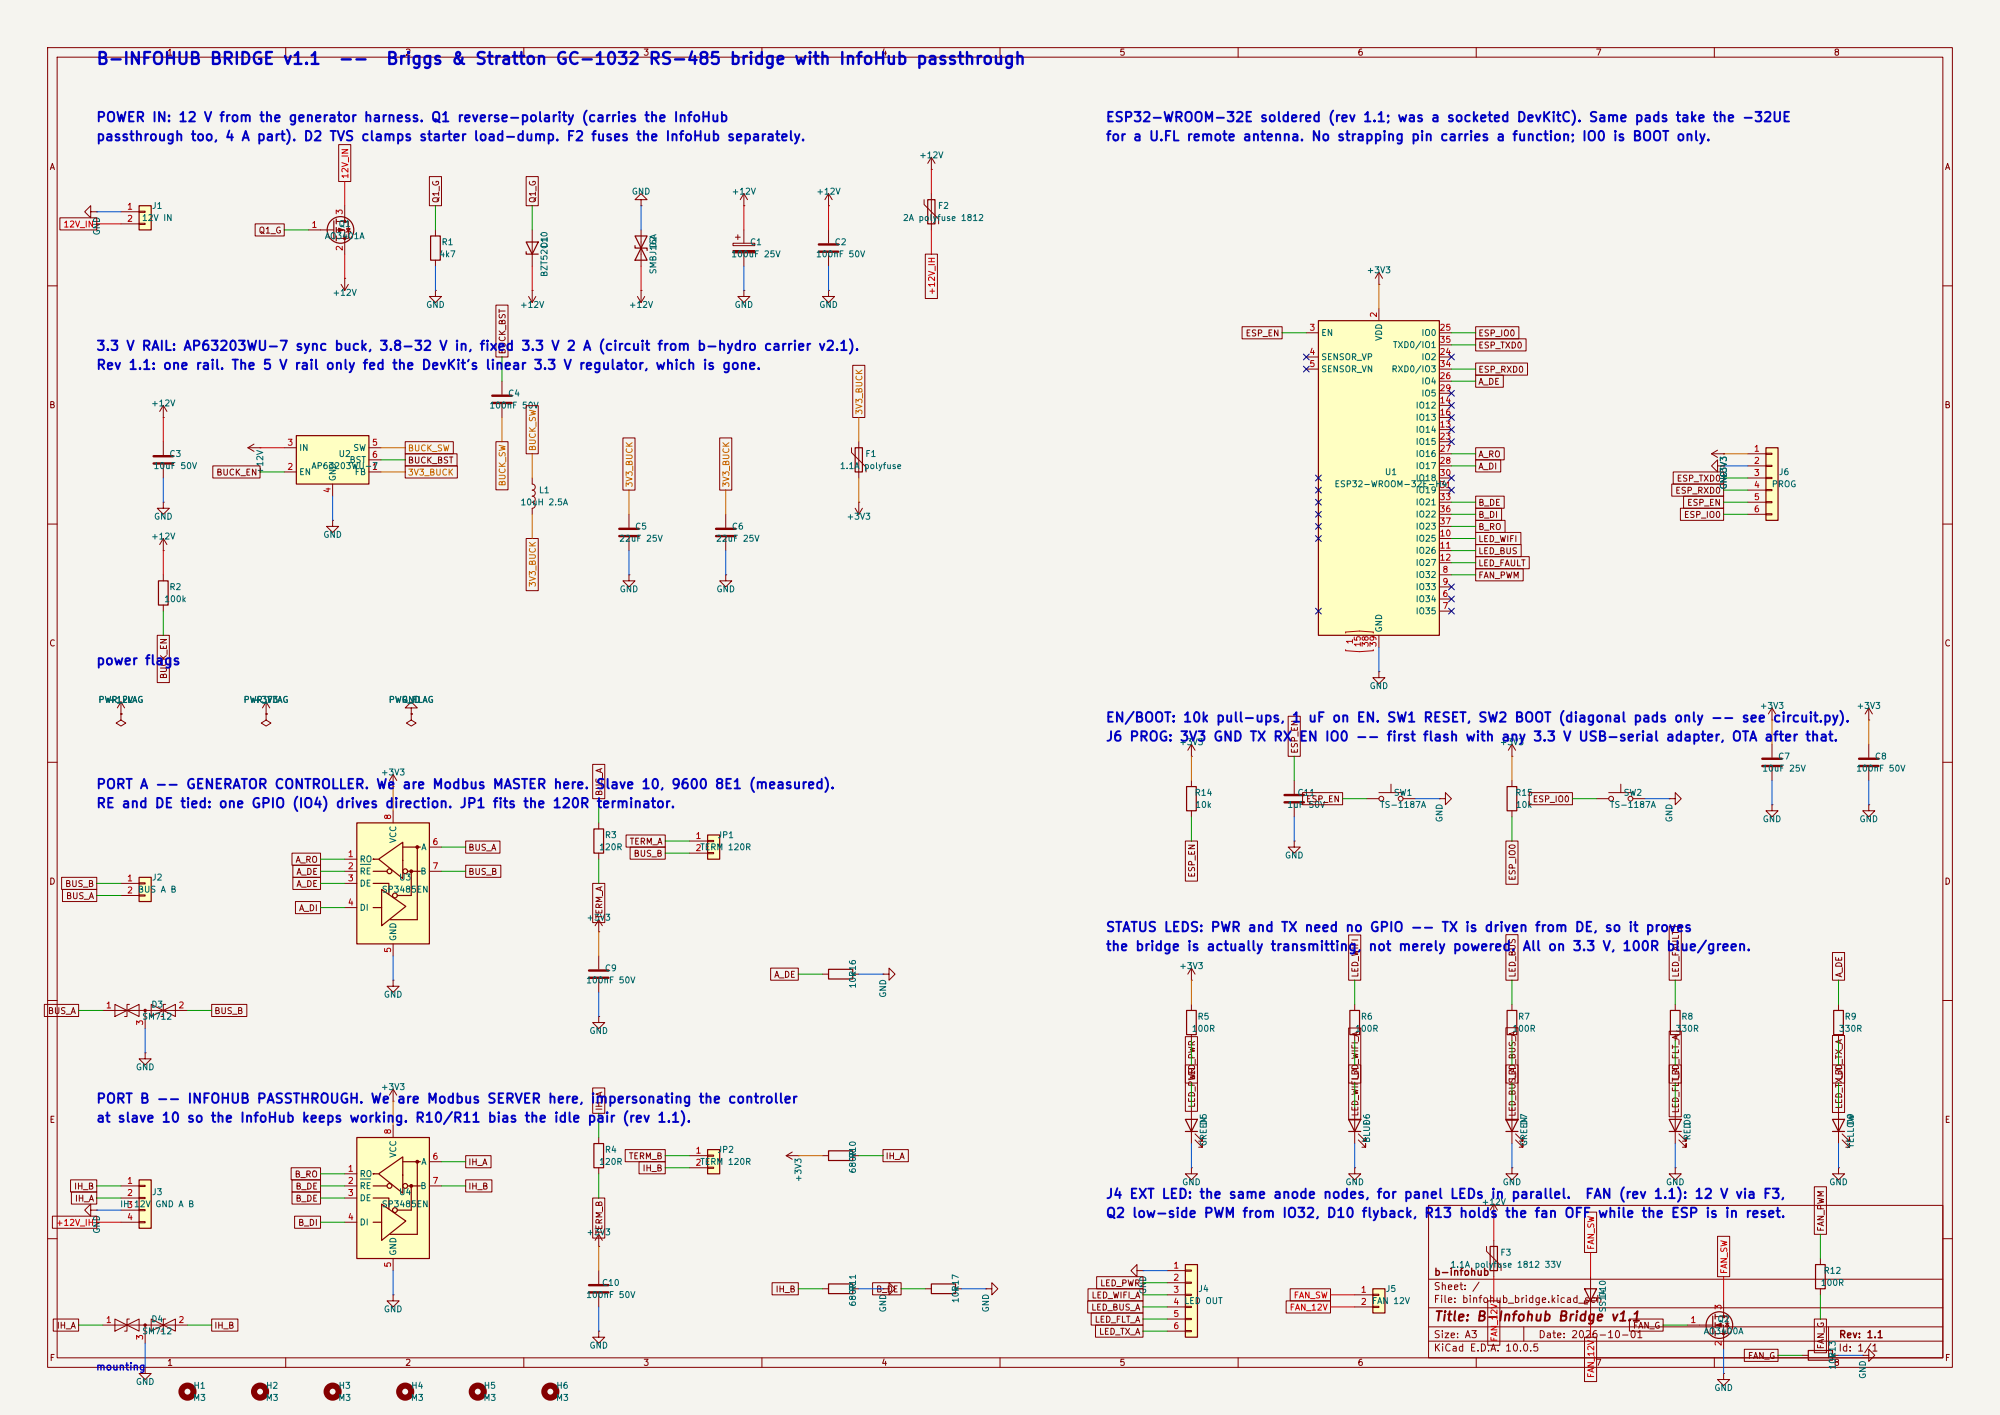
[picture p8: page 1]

B-INFOHUB BRIDGE v1.1 -- Briggs & Stratton GC-1032 RS-485 bridge with InfoHub passthrough

POWER IN: 12 V from the generator harness. Q1 reverse-polarity (carries the InfoHub
passthrough too, 4 A part). D2 TVS clamps starter load-dump. F2 fuses the InfoHub separately.

ESP32-WROOM-32E soldered (rev 1.1; was a socketed DevKitC). Same pads take the -32UE
for a U.FL remote antenna. No strapping pin carries a function; IO0 is BOOT only.

3.3 V RAIL: AP63203WU-7 sync buck, 3.8-32 V in, fixed 3.3 V 2 A (circuit from b-hydro carrier v2.1).
Rev 1.1: one rail. The 5 V rail only fed the DevKit's linear 3.3 V regulator, which is gone.
100k +12V +12V GND

RE and DE tied: one GPIO (IO4) drives direction. JP1 fits the 120R terminator.

STATUS LEDS: PWR and TX need no GPIO -- TX is driven from DE, so it proves

at slave 10 so the InfoHub keeps working. R10/R11 bias the idle pair (rev 1.1).

J4 EXT LED: the same anode nodes, for panel LEDs in parallel. FAN (rev 1.1): 12 V via F3,

Size: A3 | AO3400A | | Rev: 1.1 | F Date: 2026-10-01
KiCad E.D.A. 10.0.5 | | Id: 1/1

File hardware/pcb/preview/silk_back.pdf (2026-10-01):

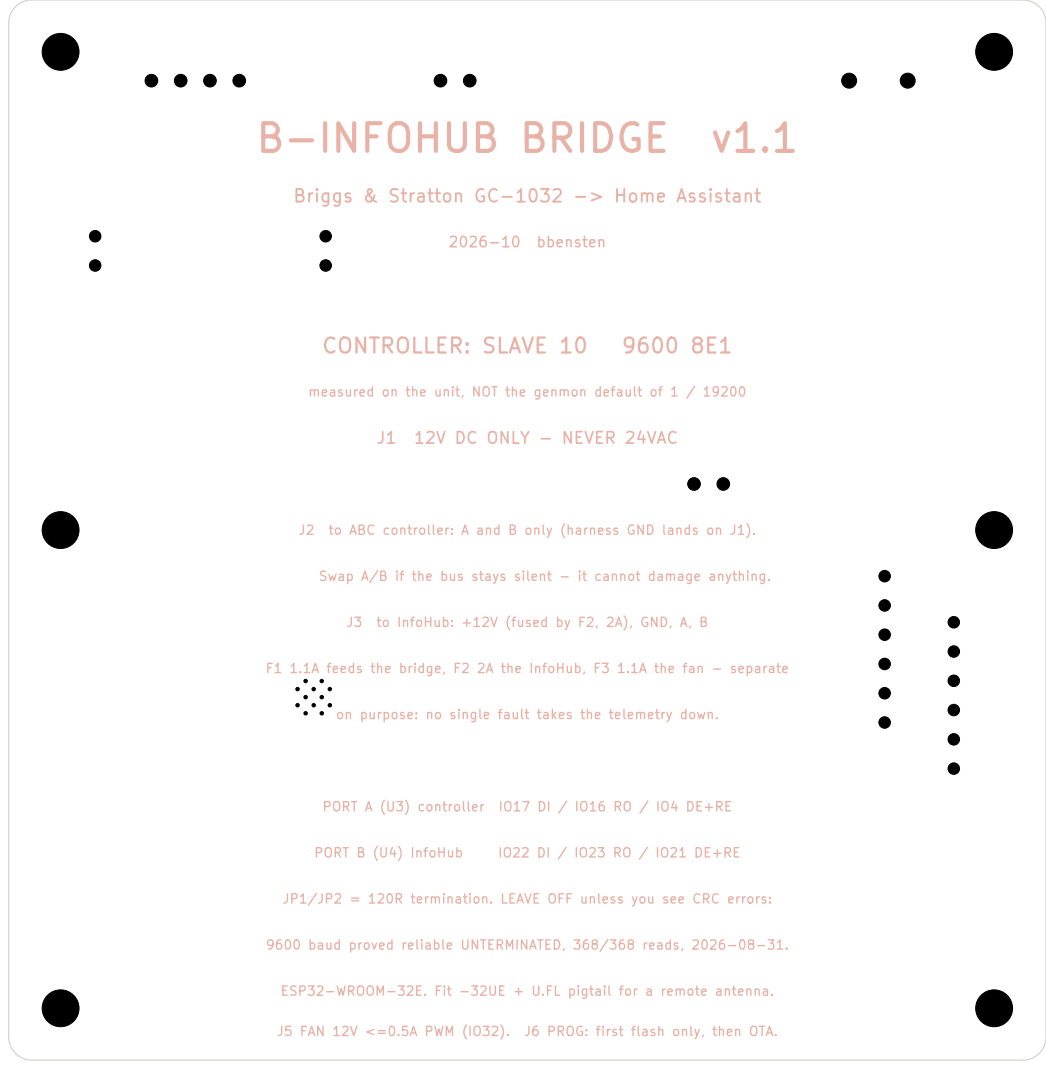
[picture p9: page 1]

measured on the unit, NOT the genmon default of 1 / 19200 J1 12V DC ONLY - NEVER 24VAC

J2 to ABC controller: A and B only (harness GND lands on J1). Swap A/B if the bus stays silent - it cannot damage anything. J3 to InfoHub: +12V (fused by F2, 2A), GND, A, B

JP1/JP2 = 120R termination. LEAVE OFF unless you see CRC errors: 9600 baud proved reliable UNTERMINATED, 368/368 reads, 2026-08-31. ESP32-WROOM-32E. Fit -32UE + U.FL pigtail for a remote antenna. J5 FAN 12V <=0.5A PWM (IO32). J6 PROG: first flash only, then OTA.

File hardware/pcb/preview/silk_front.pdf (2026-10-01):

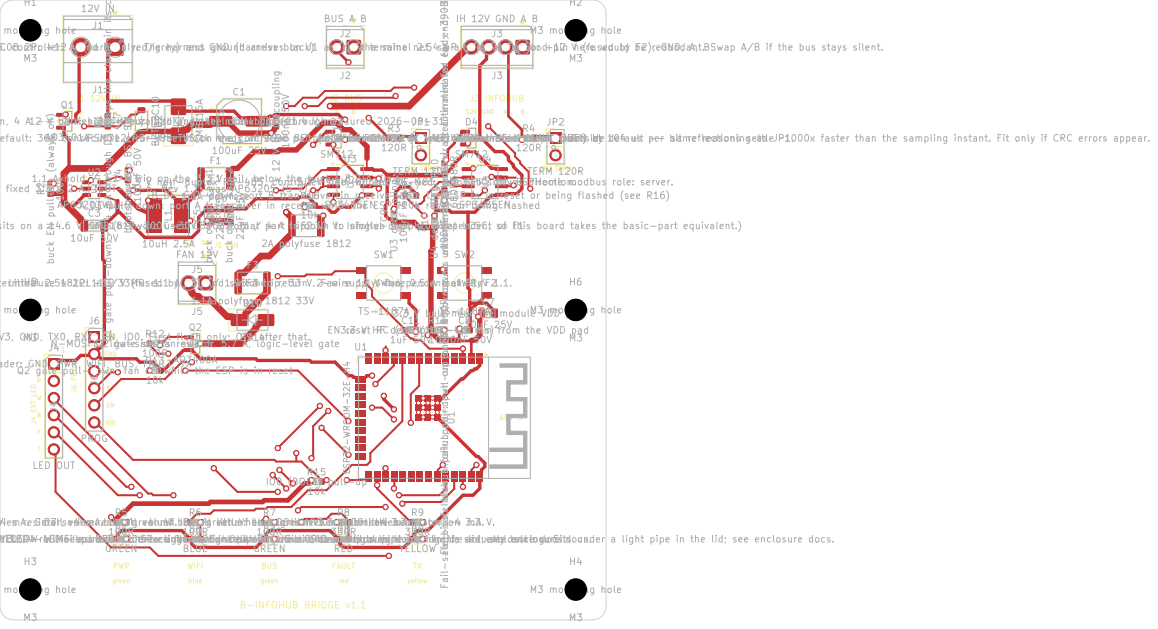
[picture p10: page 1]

100nF 50V 3.3 V HF decoupling, 4.5 mm from the VDD pad C8 R14

D5 series resistor, ~4 mA. Small value: blue/green Vf leaves little headroom on 3.3 V. R5 D5 GREEN

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

D8 series resistor, ~4 mA. R8 D8 RED

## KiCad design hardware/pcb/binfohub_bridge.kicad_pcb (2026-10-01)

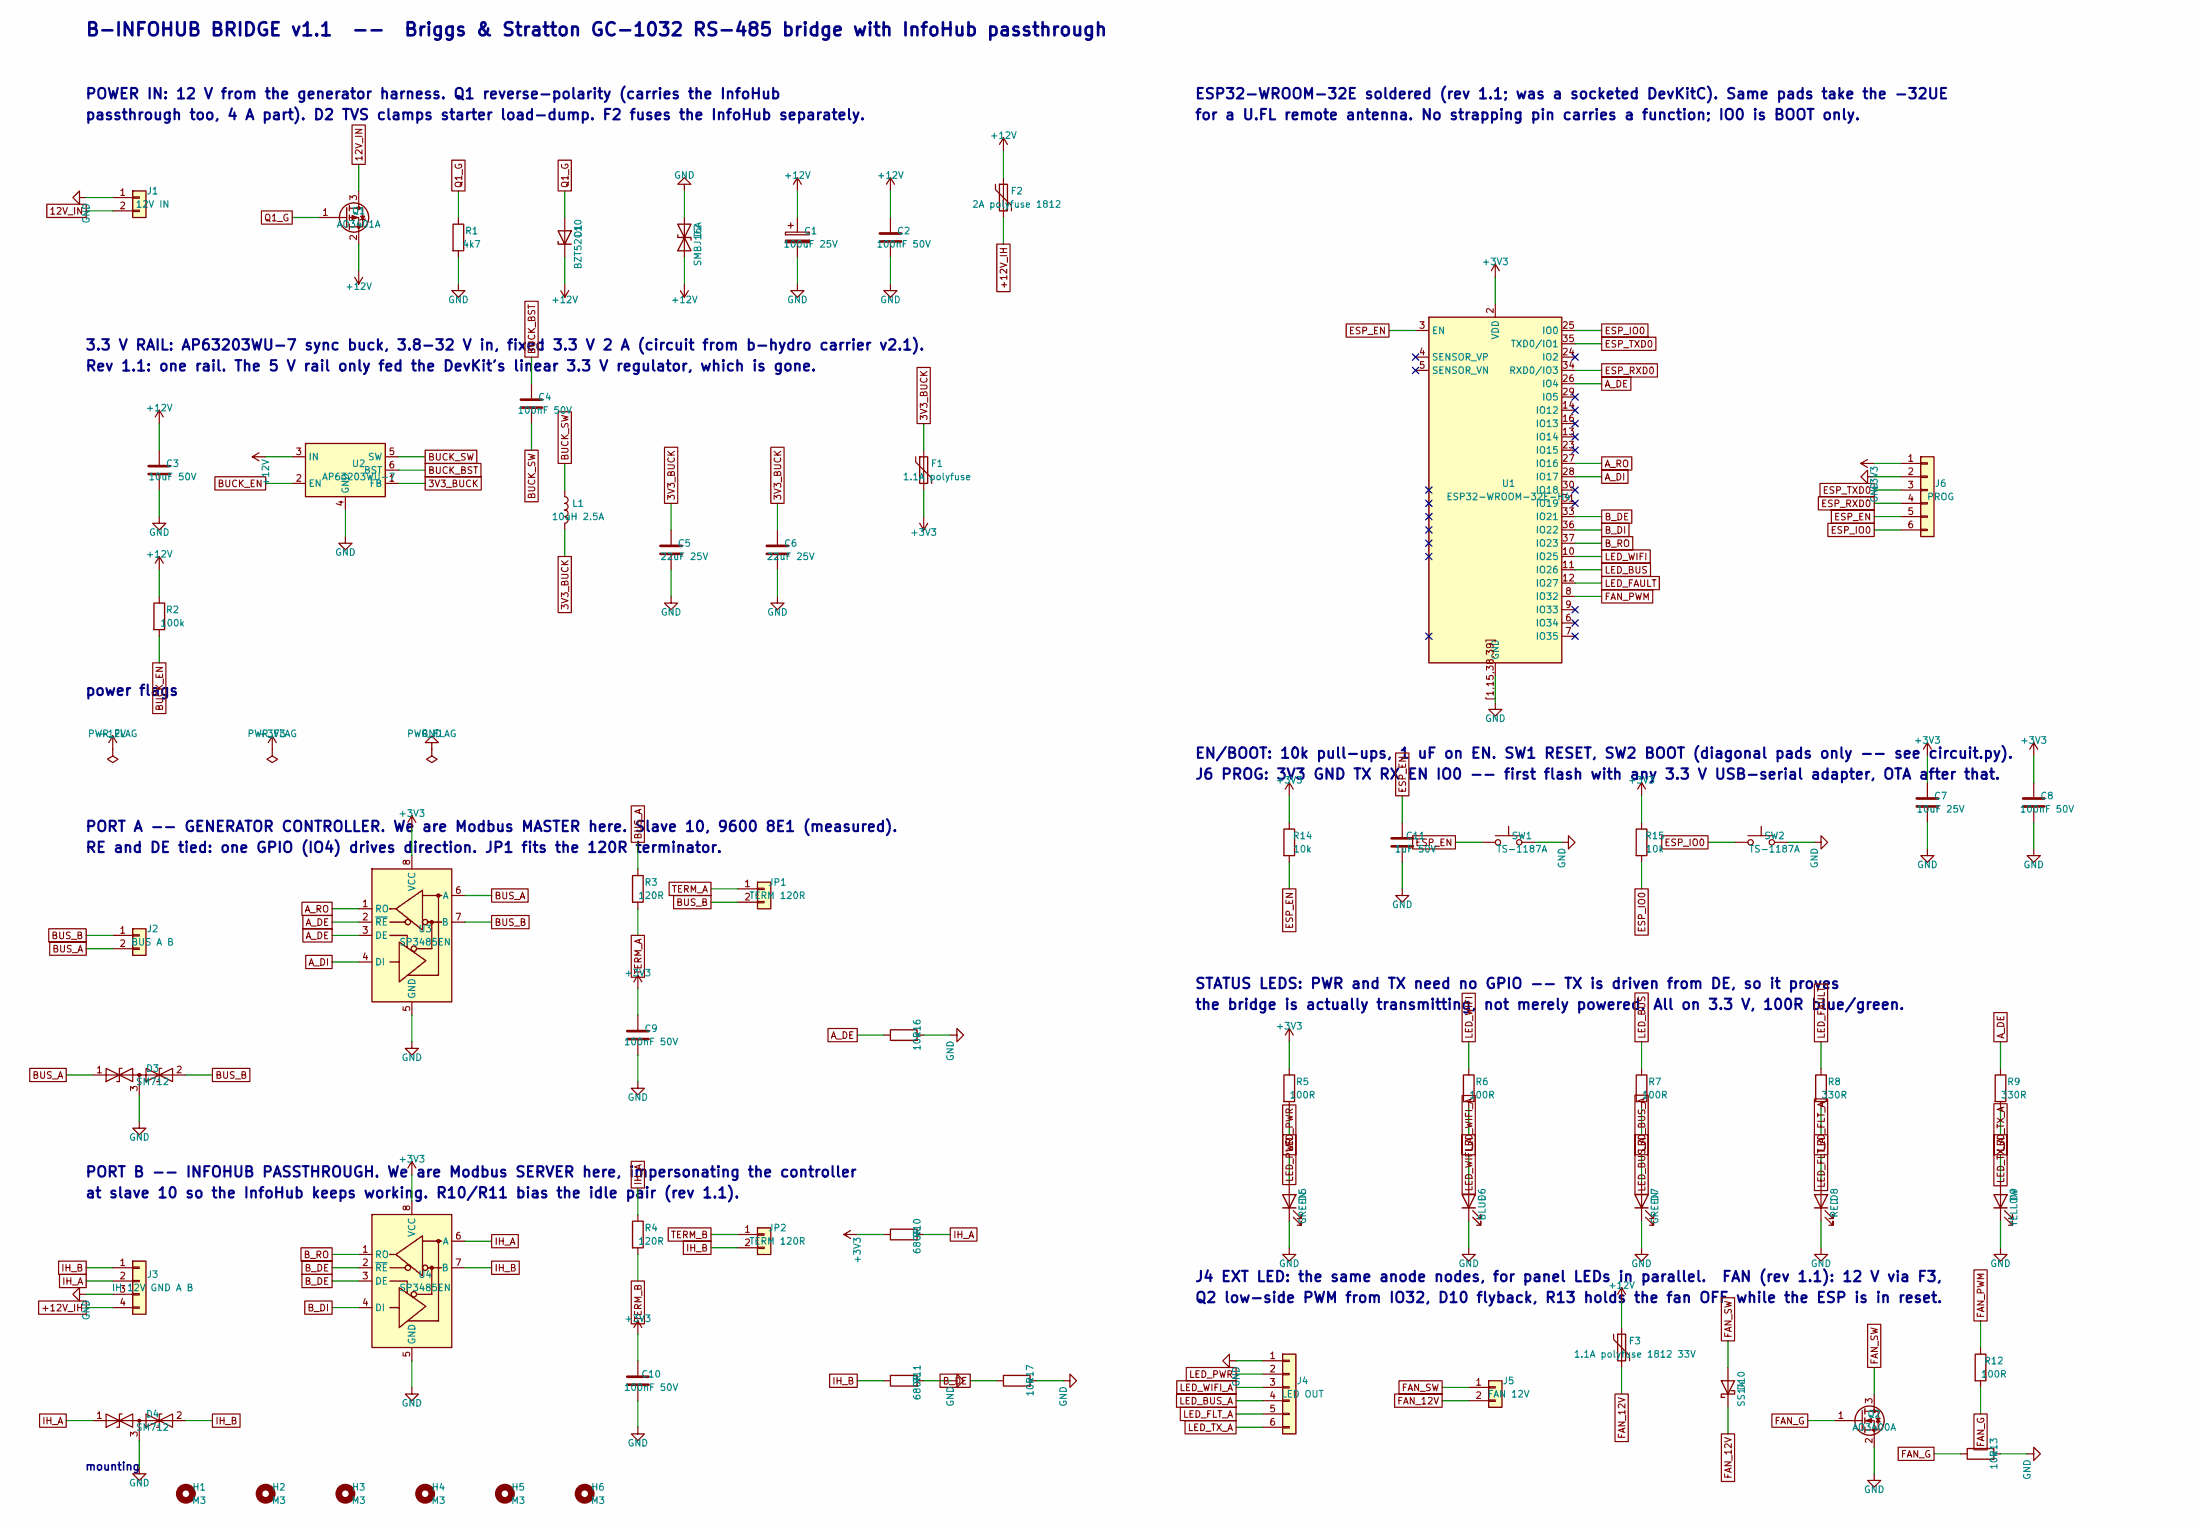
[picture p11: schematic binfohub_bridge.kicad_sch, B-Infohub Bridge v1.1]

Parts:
C1: 100uF 25V; CP_Elec_6.3x7.7; LCSC C3338
C2, C4, C8, C9, C10: 100nF 50V; C_0603_1608Metric; LCSC C14663
C3: 10uF 50V; C_1206_3216Metric; LCSC C13585
C5, C6: 22uF 25V; C_0805_2012Metric; LCSC C45783
C7: 10uF 25V; C_0805_2012Metric; LCSC C15850
C11: 1uF 50V; C_0603_1608Metric; LCSC C15849
D1: BZT52C10; D_SOD-123; LCSC C173431
D2: SMBJ16A; D_SMB; LCSC C353386
D3, D4: SM712; SOT-23; LCSC C32677
D5, D7: GREEN; LED_0603_1608Metric; LCSC C965804
D6: BLUE; LED_0603_1608Metric; LCSC C965807
D8: RED; LED_0603_1608Metric; LCSC C2286
D9: YELLOW; LED_0603_1608Metric; LCSC C965803
D10: SS14; D_SMA; LCSC C2480
F1: 1.1A polyfuse; Fuse_1812_4532Metric; LCSC C883148
F2: 2A polyfuse 1812; Fuse_1812_4532Metric; LCSC C2760293
F3: 1.1A polyfuse 1812 33V; Fuse_1812_4532Metric; LCSC C142747
H1, H2, H3, H4, H5, H6: M3; MountingHole_3.2mm_M3
J1: 12V IN; TerminalBlock_Phoenix_MKDS-1,5-2-5.08_1x02_P5.08mm_Horizont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; LCSC C474881
J2: BUS A B; TerminalBlock_Phoenix_MPT-0,5-2-2.54_1x02_P2.54mm_Horizontal; LCSC C474920
J3: IH 12V GND A B; TerminalBlock_Phoenix_MPT-0,5-4-2.54_1x04_P2.54mm_Horizontal; LCSC C474922
J4: LED OUT; PinHeader_1x06_P2.54mm_Vertical; LCSC C492405
J5: FAN 12V; TerminalBlock_Phoenix_MPT-0,5-2-2.54_1x02_P2.54mm_Horizontal; LCSC C474920
J6: PROG; PinHeader_1x06_P2.54mm_Vertical; LCSC C492405
JP1, JP2: TERM 120R; PinHeader_1x02_P2.54mm_Vertical; LCSC C492401
L1: 10uH 2.5A; L_Bourns_SRN6045TA; LCSC C79272
Q1: AO3401A; SOT-23; LCSC C15127
Q2: AO3400A; SOT-23; LCSC C20917
R1: 4k7; R_0603_1608Metric; LCSC C23162
R2: 100k; R_0603_1608Metric; LCSC C25803
R3, R4: 120R; R_0603_1608Metric; LCSC C22787
R5, R6, R7, R12: 100R; R_0603_1608Metric; LCSC C22775
R8, R9: 330R; R_0603_1608Metric; LCSC C23138
R10, R11: 680R; R_0603_1608Metric; LCSC C23228
R13, R14, R15, R16, R17: 10k; R_0603_1608Metric; LCSC C25804
SW1, SW2: TS-1187A; SW_TS-1187A; LCSC C318884
U1: ESP32-WROOM-32E-H4; ESP32-WROOM-32E_edge; LCSC C3013935
U2: AP63203WU-7; TSOT-23-6; LCSC C780769
U3, U4: SP3485EN; SOIC-8_3.9x4.9mm_P1.27mm; LCSC C8963

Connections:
3V3_BUCK: C5.1, C6.1, F1.1, L1.2, U2.1 (FB)
12V_IN: J1.2, Q1.3 (D)
+3V3: C7.1, C8.1, C9.1, C10.1, F1.2, J6.1, R5.1, R10.1, R14.1, R15.1, U1.2 (VDD), U3.8 (VCC), U4.8 (VCC)
+12V: C1.1, C2.1, C3.1, D1.1 (K), D2.1 (A1), F2.1, F3.1, Q1.2 (S), R2.1, U2.3 (IN)
+12V_IH: F2.2, J3.4
A_DE: R9.1, R16.1, U1.26 (IO4), U3.2 (~RE), U3.3 (DE)
A_DI: U1.28 (IO17), U3.4 (DI)
A_RO: U1.27 (IO16), U3.1 (RO)
BUCK_BST: C4.1, U2.6 (BST)
BUCK_EN: R2.2, U2.2 (EN)
BUCK_SW: C4.2, L1.1, U2.5 (SW)
BUS_A: D3.1 (A1), J2.2, R3.1, U3.6 (A)
BUS_B: D3.2 (A2), J2.1, JP1.2, U3.7 (B)
B_DE: R17.1, U1.33 (IO21), U4.2 (~RE), U4.3 (DE)
B_DI: U1.36 (IO22), U4.4 (DI)
B_RO: U1.37 (IO23), U4.1 (RO)
ESP_EN: C11.1, J6.5, R14.2, SW1.1, U1.3 (EN)
ESP_IO0: J6.6, R15.2, SW2.1, U1.25 (IO0)
ESP_RXD0: J6.4, U1.34 (RXD0/IO3)
ESP_TXD0: J6.3, U1.35 (TXD0/IO1)
FAN_12V: D10.1 (K), F3.2, J5.2
FAN_G: Q2.1 (G), R12.2, R13.1
FAN_PWM: R12.1, U1.8 (IO32)
FAN_SW: D10.2 (A), J5.1, Q2.3 (D)
GND: C1.2, C2.2, C3.2, C5.2, C6.2, C7.2, C8.2, C9.2, C10.2, C11.2, D2.2 (A2), D3.3 (common), D4.3 (common), D5.1 (K), D6.1 (K), D7.1 (K), D8.1 (K), D9.1 (K), J1.1, J3.3, J4.1, J6.2, Q2.2 (S), R1.2, R11.2, R13.2, R16.2, R17.2, SW1.2, SW2.2, U1.1, U1.15, U1.38, U1.39, U1.[1,15,38,39] (GND), U2.4 (GND), U3.5 (GND), U4.5 (GND)
IH_A: D4.1 (A1), J3.2, R4.1, R10.2, U4.6 (A)
IH_B: D4.2 (A2), J3.1, JP2.2, R11.1, U4.7 (B)
LED_BUS: R7.1, U1.11 (IO26)
LED_BUS_A: D7.2 (A), J4.4, R7.2
LED_FAULT: R8.1, U1.12 (IO27)
LED_FLT_A: D8.2 (A), J4.5, R8.2
LED_PWR: D5.2 (A), J4.2, R5.2
LED_TX_A: D9.2 (A), J4.6, R9.2
LED_WIFI: R6.1, U1.10 (IO25)
LED_WIFI_A: D6.2 (A), J4.3, R6.2
Q1_G: D1.2 (A), Q1.1 (G), R1.1
TERM_A: JP1.1, R3.2
TERM_B: JP2.1, R4.2

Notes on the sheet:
B-INFOHUB BRIDGE v1.1 -- Briggs & Stratton GC-1032 RS-485 bridge with InfoHub passthrough
POWER IN: 12 V from the generator harness. Q1 reverse-polarity (carries the InfoHub
passthrough too, 4 A part). D2 TVS clamps starter load-dump. F2 fuses the InfoHub separately.
3.3 V RAIL: AP63203WU-7 sync buck, 3.8-32 V in, fixed 3.3 V 2 A (circuit from b-hydro carrier v2.1).
Rev 1.1: one rail. The 5 V rail only fed the DevKit's linear 3.3 V regulator, which is gone.
power flags
PORT A -- GENERATOR CONTROLLER. We are Modbus MASTER here. Slave 10, 9600 8E1 (measured).
RE and DE tied: one GPIO (IO4) drives direction. JP1 fits the 120R terminator.
PORT B -- INFOHUB PASSTHROUGH. We are Modbus SERVER here, impersonating the controller
at slave 10 so the InfoHub keeps working. R10/R11 bias the idle pair (rev 1.1).
mounting
ESP32-WROOM-32E soldered (rev 1.1; was a socketed DevKitC). Same pads take the -32UE
for a U.FL remote antenna. No strapping pin carries a function; IO0 is BOOT only.
EN/BOOT: 10k pull-ups, 1 uF on EN. SW1 RESET, SW2 BOOT (diagonal pads only -- see circuit.py).
J6 PROG: 3V3 GND TX RX EN IO0 -- first flash with any 3.3 V USB-serial adapter, OTA after that.
STATUS LEDS: PWR and TX need no GPIO -- TX is driven from DE, so it proves
the bridge is actually transmitting, not merely powered. All on 3.3 V, 100R blue/green.
J4 EXT LED: the same anode nodes, for panel LEDs in parallel. FAN (rev 1.1): 12 V via F3,
Q2 low-side PWM from IO32, D10 flyback, R13 holds the fan OFF while the ESP is in reset.

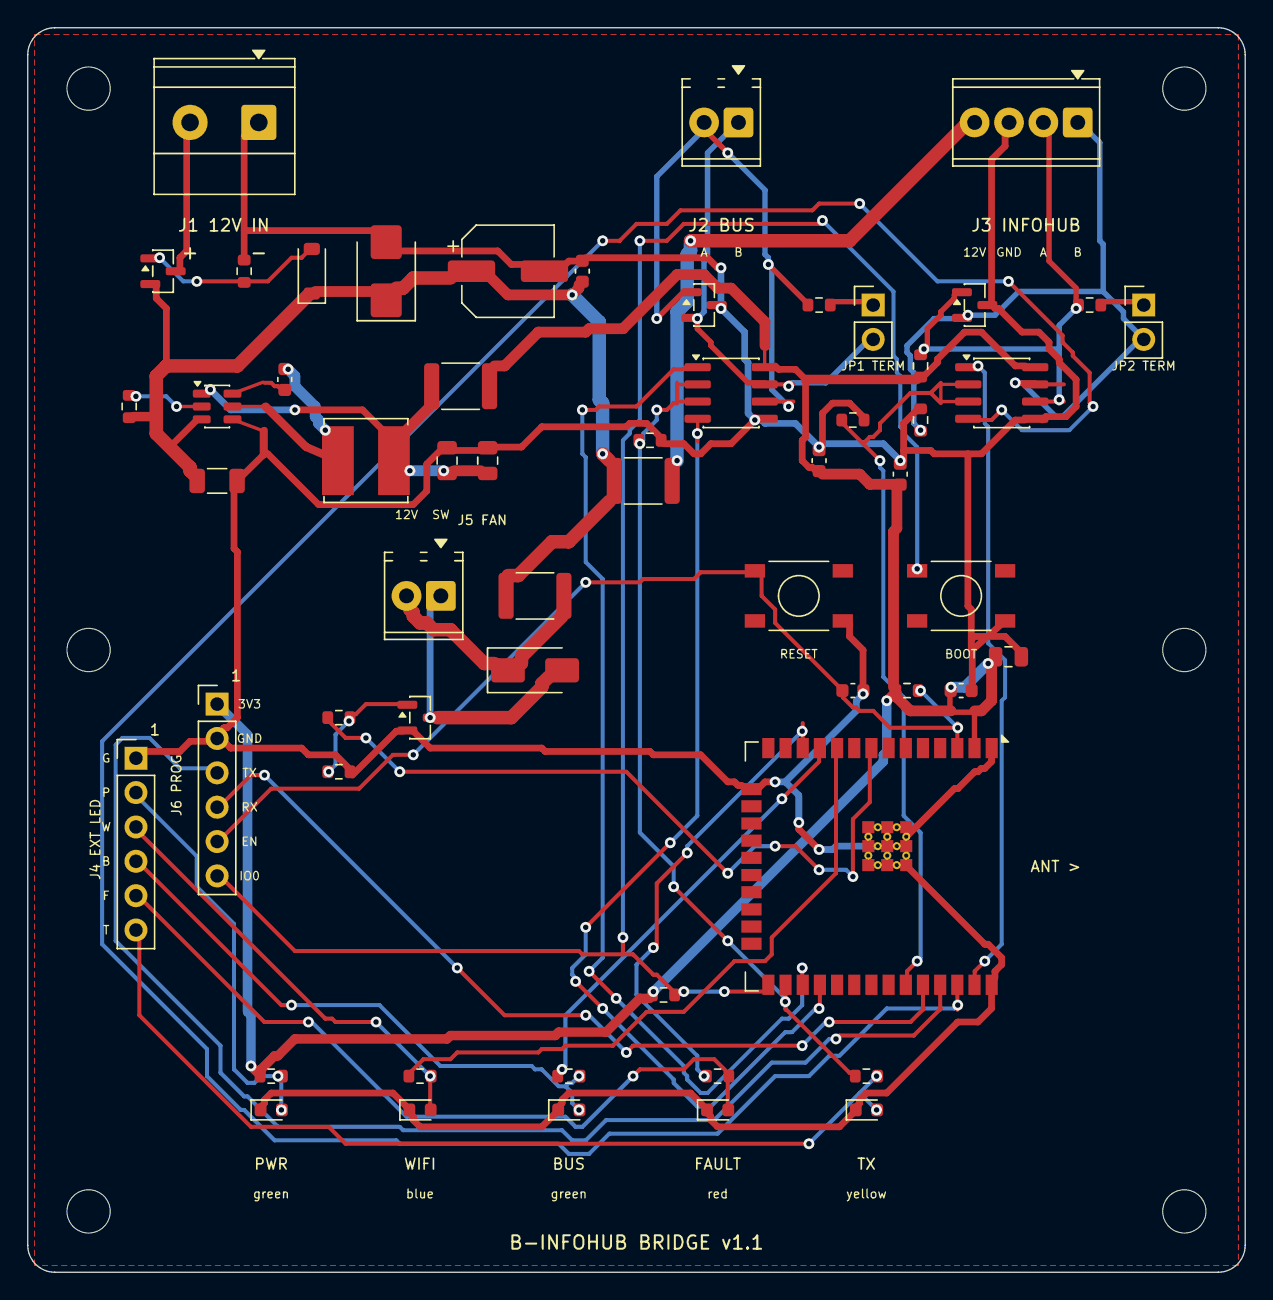
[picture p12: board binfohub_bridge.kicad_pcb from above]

Board: 2 copper layers, 90.0 x 92.0 mm, 64 parts (0 on the bottom side), 38 nets.

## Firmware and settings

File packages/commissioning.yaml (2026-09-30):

# Commissioning: learn what THIS controller answers, then run on that knowledge.
#
# WHY
#
# This firmware was written against one GC-1032. genmon's own definition says
# register presence varies across the GC-1030 family -- "these registers show
# data in some models yet the controller does not respond in others" -- and
# the first other unit we looked at (a cellular InfoHub on a GC controller)
# reports a visibly different field set to the cloud. A bridge going out in
# the wild has to discover the generator it is plugged into rather than
# assume it is Brent's. See ../docs/discovery.md.
#
# WHAT IT DOES (all reads, FC04 only, nothing ever written)
#
#   1. Identity   0x0000 protocol revision, 0x0055 firmware, 0x00B5 model
#                 (0x00B5 is documented to answer on some controllers and
#                 time out on others -- either outcome is information).
#   2. Presence   The poller's six ranges are proven by their own sensors
#                 having values (a range that returns an exception every cycle
#                 never populates them). The probe asks only about what the
#                 poller does not read: the ten gaps inside 0x0000-0x0056 that
#                 genmon says vary by model, and the alt block 0x00B4-0x00CE
#                 as four reads. One command in flight at a time; after any
#                 miss, a heartbeat read of 0x0000 that also carries the
#                 protocol revision.
#   3. Baseline   the alarm block 0x0040-0x004D as it reads on this machine
#                 at rest, per nibble: F = not present, 1 = wired and OK,
#                 0 = INDETERMINATE (shown, never treated as a fault),
#                 anything else = unexpected. See ../docs/alarm-encoding.md
#                 for why this is an inventory and not a decode.
#   4. Plausibility  battery 8-16 V, utility 0 or 90-140 V per leg -- a range
#                 that answers with nonsense is marked, not trusted.
#
# The result is a PROFILE, persisted in flash, published as one compact JSON
# string plus three scalars. It runs ONCE, by itself, the first time the bus
# is healthy with the engine stopped and no profile is stored; and again on
# the Run Discovery button. It never runs while the engine turns.
#
# WHAT IT CANNOT KNOW, STATED PLAINLY
#
# ESPHome hands a custom command's callback the DATA of a reply. An exception
# reply ("illegal address") only reaches an internal log line, and a timeout
# reaches nothing. So each register is "answered" or "did not answer" -- the
# firmware cannot tell a controller that refuses an address from one that
# stays silent. That is fine here: bus_healthy already proves the wiring, so
# "did not answer" means the register is not there for this controller.
#
# SAFETY ENVELOPE -- inherited from holding-sweep.yaml, which learned it the
# hard way (its first version interleaved probe reads with the poll loop and
# took telemetry down inside four minutes):
#
#   * takes the bus EXCLUSIVELY: stop_poller() first, start_poller() after;
#   * REFUSES to run while the engine is turning;
#   * ~16 probes plus heartbeats, one in flight at a time, RETRIES OFF for the
#     duration: a present register answers in tens of ms, an absent one costs
#     one send-wait (~250 ms) plus a heartbeat. Worst case ~10 s, inside
#     bus_healthy's 30 s tolerance, so Home Assistant never sees the bus
#     blink. The first version queued 114 commands with retries on and no
#     heartbeat; the controller was marked offline, its queue was cleared,
#     and the bus was dead for three minutes. A watchdog forces polling back
#     on at 3 minutes whatever happens, under the 5-minute bridge-dark alert;
#   * no per-register entities: the board runs near 82% RAM. Two entities,
#     total -- the profile string and the button.
#
# PASSTHROUGH IS UNAFFECTED. Port B answers the InfoHub from cached values,
# never from the wire, so the InfoHub sees a normal bus throughout.
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

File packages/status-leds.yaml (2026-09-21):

# On-board status LEDs (B-Infohub bridge PCB rev 1.0)
#
# These are the only feedback you get standing at the generator with no network,
# which is exactly the situation during first bring-up. They are worth getting
# right.
#
# Five indicators, read through light pipes in the enclosure lid. Two are wired
# so they cannot lie, and need no firmware:
#
#   D5 PWR    green   hard-wired to the 5 V rail. Dark means the buck is dead,
#                     and no amount of firmware would have told you that.
#   D9 TX     yellow  driven from the RS-485 DE line (GPIO4). Flashes on every
#                     transmission with no GPIO and no code, so it proves the
#                     bridge is TALKING rather than merely powered.
#
#   D6 WIFI   blue    GPIO25   D7 BUS  green  GPIO26   D8 FAULT  red  GPIO27
#
# WHAT CHANGED, AND WHY IT MATTERED
#
# The BUS LED used to be `!isnan(alarm_reg_4f.state)`, on the theory that a
# dropped Modbus link stops publishing and the state goes NaN. It does not.
# ESPHome sensors RETAIN their last value when a poll fails -- nothing resets
# them -- so that LED would have sat there solid green with the RS-485 pair
# cut, which is the single most misleading thing an indicator can do during
# bring-up.
#
# It now reads `bus_healthy` from packages/diagnostics.yaml, which is measured
# the one way that cannot lie: time since a register last arrived.
#
# READING THE LIGHTS
#
# Three LEDs, four states each. The patterns are chosen so the states that
# demand DIFFERENT ACTIONS never look alike -- that is the whole job of an
# indicator, and the reason "off" is never used for two different meanings.
#
#   WIFI (blue)
#     solid        on the network -- confirmation the instant Wi-Fi associates
#     solid with   on the network AND Home Assistant connected: a brief wink
#     a wink       every 2 s, so "fully working" is visibly alive
#     fast 2 Hz    setup AP is up -- join "b-infohub Setup" and configure
#     off          no network and no AP: associating, or the radio is down
#
#   BUS (green)
#     solid        controller answering cleanly
#     double-pulse healthy AND serving an InfoHub through the proxy
#     slow 1 Hz    answering, but missing polls (success rate under 90%)
#                  -> wiring, termination or turnaround time
#     off          NOTHING HEARD -- check pair, address, baud, parity
#
#   FAULT (red)
#     fast 2 Hz    SAFE MODE -- repeated bad boots. Push firmware, not a
#                  spanner. Takes priority over everything else.
#     solid        generator shut down or tripped
#     slow 1 Hz    warning only: running, but something wants attention
#     off          clear
#
# On boot all three sweep once. That proves the LEDs, the light pipes and the
# GPIOs in one go -- worth having when the board is already sealed in a box.
#
# BRIGHTNESS
#
# The three GPIO LEDs are on LEDC (hardware PWM), capped by the "Status LED
# Brightness" slider. It caps max_power, so every rule below -- set_state,
# turn_on, the boot sweep, the reset-button identify -- dims with it and
# none of them need to know. PWR and TX are wired without a GPIO and cannot
# be dimmed here; that takes a bigger R5 / R9.
#
# The floor is 5%, not 0: "off" already means something on every one of these
# LEDs, and a slider that could make them all dark would make them all lie.
# Default is 100%, which is exactly the old on/off drive. The resistors were
# sized so the LEDs read through light pipes in daylight -- judge a lower
# setting through the lid, not on the bench.

esphome:
  on_boot:
    # Sweep once at startup. Proves all three LEDs, their series resistors, the
    # light pipes and the GPIOs -- in a sealed outdoor box that is the only
    # chance you get to check them without opening it.
    - priority: -100
      then:
        # Apply the restored brightness before the sweep, so the sweep shows
        # the level the LEDs will actually run at.
        - script.execute: apply_led_brightness
        - repeat:
            count: 2
            then:
              - output.turn_on: led_wifi
              - delay: 120ms
              - output.turn_off: led_wifi
              - output.turn_on: led_bus
              - delay: 120ms
              - output.turn_off: led_bus
              - output.turn_on: led_fault
              - delay: 120ms
              - output.turn_off: led_fault

output:
  # max_power is stated explicitly because ESPHome only compiles in the
  # scaling that set_max_power() needs when some output declares it. 100% is
  # the pre-boot value; the slider takes over as soon as the script runs.
  - platform: ledc
    pin: GPIO25
    id: led_wifi
    max_power: 100%
  - platform: ledc
    pin: GPIO26
    id: led_bus
    max_power: 100%
  - platform: ledc
    pin: GPIO27
    id: led_fault
    max_power: 100%
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

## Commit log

2026-09-18 Initial commit: B-Infohub RS-485 bridge for the Briggs & Stratton GC-1032
    An ESP32 + dual SP3485 board that reads a whole-home generator's Modbus
    bus directly, so Home Assistant gets local telemetry without a cloud
    subscription -- while the original InfoHub keeps working behind it as
    out-of-band cell backup.
    hardware/pcb KiCad schematic, layout, gerbers, JLC fab package
    packages/ ESPHome config: two RS-485 ports, one master and one
    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
    [binfohub_bridge-B_Courtyard.gbr, binfohub_bridge-B_Cu.gbl, binfohub_bridge-B_Fab.gbr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]
2026-09-19 docs: package this so someone without a toolchain can install it
    The README was a bring-up log. It opened with a status table saying the
    firmware was 'not yet flashed', described 51 alarms when the shipped set
    is 34, and told the reader to run esphome from a checkout. None of that
    is useful to someone who just wants their generator in Home Assistant,
    and the bits that were wrong were wrong in a way that would stop them
    trying. Preserved verbatim as docs/development.md.
    THE INSTALL PATH IS NOW A WEB PAGE.
    install/ is an esp-web-tools page that flashes the board over Web Serial
    straight from a browser -- no Python, no PlatformIO, no clone. The
    firmware was already built for this (no network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
2026-09-19 fix: the weekly exercise is not a fault
    Caught live, mid-run: active_alarm_count 2, fault on, and the only two
    bits asserted were 'exercising' and 'scheduled exercise in progress'.
    They live in the same alarm nibbles as real faults, so they were swept
    in with them and counted. active_alarm_count > 0 sets the 'fault' flag,
    which turns the generator tile red and fires GeneratorFaultActive -- for
    the machine doing exactly what it is supposed to do once a week.
    The Grafana push already excluded these two by hand, which fixed the
    symptom one layer downstream and left the cause in place. This is the
    cause.
    NOT_A_FAULT is keyed by ESPHome ID, not object_id: the filter is
    'i not in NOT_A_FAULT' w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
2026-09-19 Publish controller clock skew, its clock, and the raw status word
    Three diagnostics the bridge already produced and Home Assistant never
    saw, plus the timezone fix that made the exercise timestamps wrong.
    CLOCK SKEW is new. The controller runs its exercise schedule against its
    OWN clock, so drift moves the weekly test while nothing downstream
    notices -- every timestamp Home Assistant produces uses HA's clock and is
    perfectly consistent with itself. Measured -94 minutes when the sensor
    was added: a weekly exercise configured for 09:30 had been firing at
    11:03, and the only reason anyone knew was that the owner said so.
    STATUS REGISTER RAW matters for what has not been decoded yet. Register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
2026-09-19 ESP32 health: heap, fragmentation, loop time; publish bus and boot evidence
    The bridge has never published heap telemetry, despite running out of
    heap once and being saved by OTA rollback, and despite every change
    since being argued in terms of RAM. The `debug:` component was not
    present at all.
    Three sensors, not the whole suite, because the board is at ~81% RAM:
    free heap, largest free block and loop time. The block size is the one
    that matters: measured live, 96.3 KB free of which 32 KB is contiguous.
    The original failure was a contiguous allocation refused while free
    memory looked fine, and total-free alone could never have shown it.
    Also now published through the contract: bus_success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
2026-09-19 Release workflow: let it enable GitHub Pages on first run
    The first release of a fresh repository built and attached the firmware
    correctly and then failed the whole job on actions/configure-pages, which
    returns a bare "Not Found" when no Pages site exists yet. Nothing in the
    message says "create one".
    `enablement: true` makes the action create the site, so cloning this repo
    and cutting a release works without a manual step in the web UI first --
    which matters because the install page IS the install instructions for
    anyone without a toolchain.
    Claude-Session: https://claude.ai/code/session_019Xp9XJRuc9G849MTaP5Ves
2026-09-21 Status LEDs: PWM drive and a brightness slider
    WIFI, BUS and FAULT move from gpio to ledc outputs, capped by a new
    "Status LED Brightness" config number (5-100%, restored across reboots,
    default 100% = the old drive). Capping max_power means every existing
    rule dims without change. The floor is 5% because "off" already carries
    meaning on each LED. PWR and TX have no GPIO and still need R5/R9.
    Claude-Session: https://claude.ai/code/session_01ESVh7DpLzA3jfcrFtGgM8a
    [status-leds.yaml]
2026-09-21 Contract: an allowlist of bridge settings HA may change
    contract/telemetry.py gains CONTROLS, and gen.py emits them as a new
    `controls` section with each one's kind, range, category and icon. It is
    an allowlist because the bridge also has Wi-Fi, web-login and factory
    reset, which must not be one dashboard tap away, and credentials, which
    HA would hold as plain entity states.
    Allowed: LED brightness; the Restart, Reset Bus Counters, Confirm
    Firmware Good and Dump Event Log buttons; the InfoHub passthrough
    switch; MQTT enable, broker, port and Apply.
    Five buttons gain ESPHome ids so the allowlist can name them. Names,
    and so object_ids, are unchanged: the running bridge reports all ten
    contr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
    [mqtt-config.yaml]
2026-09-26 Alarm watch: publish the block we cannot decode, and shout when it moves
    No real alarm has ever been observed on this machine, and the decode rule
    behind every alarm entity comes from genmon's definition, not from this
    hardware. Three things now argue against trusting it:
    * 0x0040-0x004D are bit-for-bit static across all 368 samples of a full
    start/run/stop in captures/run-2026-08-31.csv. Only 0x004E and 0x004F
    move. Static is what configuration looks like, not alarm state.
    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
2026-09-27 Port B counters, and the two design documents
    packages/passthrough-health.yaml: InfoHub Registers Served, InfoHub
    Request Age, InfoHub Polling. Every proxy read lambda now touches two
    globals (contract/gen.py injects the line, before the passthrough check
    so a polling InfoHub is visible even with the feature off). On
    2026-09-26 the InfoHub's cloud feed went silent for a day and the only
    evidence the proxy was still answering was the byte size of echoed
    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
2026-09-29 Hardware rev 1.1 (source only): fail-safe bias on the InfoHub pair
    R10/R11: 4k7 pull-up on IH_A to +3V3 and pull-down on IH_B to GND, next
    to U4, fitted by default. A raw-frame capture on 2026-09-28 showed the
    port-B pair floating inside the receiver's dead band after every reply
    the bridge sends -- ~61 bytes of garbage 35-57 ms later -- which
    ESPHome's server reads as an incoming request and answers by dropping
    its next reply: 8 of 36 replies to the InfoHub in 75 s. The SP3485 only
    guarantees a defined output for open inputs; an idle connected pair is
    not open. Port A never shows this because the GC-1032 biases its bus.
    4k7 assumes JP2 open (the default); 560R-680R if termination is fitted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
    [circuit.py]
2026-09-30 Commissioning: learn what this controller answers, once, then run on it
    packages/commissioning.yaml probes every register 0x0000-0x0056 and the
    alt block 0x00B4-0x00CE one at a time (FC04, 300 ms apart, ~35 s) with
    the poller stopped, inside the envelope holding-sweep.yaml proved: refuses
    while the engine runs, 3-minute watchdog under the 5-minute bridge-dark
    alert, no per-register entities. It records identity (protocol revision,
    firmware, 0x00B5 model), a presence bitmap, the alarm block as read at
    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
2026-09-30 Commissioning: two entities, one interval, 150 ms probe
    The five-entity first cut aborted on its first boot -- operator new[]
    failed in the API server's overflow buffer while sending the entity list
    to a reconnecting client -- and rollback restored production. Static RAM
    was +1.0%; the board's largest free block is 32 KB and the API burst at
    connect time has to fit in it. Now: the profile string and the button
    only (the three scalars are in the JSON), the three intervals and three
    scripts collapsed to one of each with set_timeout for the 25 s finalize,
    and the probe at 150 ms so its ~17 s stays inside bus_healthy's 30 s
    tolerance. +0.5% over production.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
    [commissioning.yaml]
2026-09-30 Commissioning probe: correct frames, one in flight, verified on hardware
    What the wire log taught, each now in the code:
    * a custom command's frame carries the slave address; the first cut
    addressed slave 4 and got nothing;
    * the hub de-duplicates byte-identical frames, so a one-register
    heartbeat was absorbed into the poller's own 0x0000 read -- it reads
    two registers now;
    * the callback receives register bytes only, no byte count;
    * send_wait_time is 2000 ms, not 250: the probe sets 500 ms for its
    duration and restores 2000; misses are judged at 900 ms;
    * the poll cycle already handed to the hub keeps draining after
    stop_poller(): a 12 s settle precedes the fi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
    [commissioning.yaml]
2026-09-30 Profile carries the alarm baseline; contract carries alarm_bits
    The commissioning profile now includes alarm.base -- 0x0040-0x004D as
    read at rest, 56 hex digits -- and contract/gen.py emits alarm_bits
    (register, mask, asserted value) for every decoded alarm, lifted from the
    generated lambdas so it cannot disagree with the firmware. Together they
    let a consumer apply docs/alarm-encoding.md's four-state rule without
    the device decoding anything. Verified on hardware: the published base
    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
2026-09-30 Profile v2: under Home Assistant's 255-character sensor state limit
    The v1 string with spelled-out keys and four alarm counts was ~330
    characters; Home Assistant refuses a longer sensor state and showed
    "unknown". Short keys, counts dropped (a consumer derives them from
    base), ~237 characters on this unit.
    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
    [commissioning.yaml]
2026-09-30 Firmware 1.2.0: commissioning documented; project version bumped
    docs/discovery.md gains the implementation status, the wire-level facts
    the probe now depends on, and the profile v2 schema. README points at it.
    project.version is 1.2.0 so Home Assistant's device card stops saying
    1.0.0.
    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
2026-10-01 Firmware 1.2.1: 160 MHz and Wi-Fi modem sleep for thermal margin
    Afternoon sun on the enclosure took the die to 188 F on 2026-10-01 and port A
    started dropping one byte per reply; the bus was dead ~90 min and a fresh
    boot at the same temperature reproduced it. Night baseline is 125-135 F, so
    ~75 F of that is self-heating. Cut the two biggest sources: CPU 240->160 MHz
    and the radio out of continuous receive. Nothing time-critical rides on
    either -- both UARTs are hardware and the InfoHub is served from cache.
    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
2026-10-01 Hardware rev 1.1: bare WROOM-32E, 3.3 V rail, fan header, programming header
    Same outline, holes, terminal and LED positions as rev 1.0, so it fits the
    existing enclosure. Driven by the 2026-10-01 thermal failure: ESP32-WROOM-32E
    soldered at the right edge (antenna outward; -32UE fits the same pads for a
    U.FL remote antenna), AP63203 3.3 V buck replacing the 5 V rail and the
    DevKit's linear regulator, J5 12 V PWM fan output (IO32, AO3400A, F3, SS14),
    EN/IO0 support with RESET/BOOT and a J6 programming header, R10/R11 bias.
    ERC 0, DRC 0 errors / 0 unconnected (7 cosmetic warnings), 100 % routed
    (755 tracks / 104 vias), ground pour plotted. Rev 1.0's shipped gerbers had
    no pour (zone outlines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
    [binfohub_bridge-B_Courtyard.gbr, binfohub_bridge-B_Cu.gbl, binfohub_bridge-B_Cu.gbr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]
2026-10-01 Firmware 1.2.2: port B silent until the first full poll fills the cache
    A rebooted bridge served 0xFFFF for every register it had not read yet, and
    the InfoHub decodes all-ones in the status word as utility power failure --
    every "grid lost" the vendor cloud recorded this week lines up with a bridge
    reboot, and on 2026-10-01 a marginal bus stretched that window to eight
    minutes and paged a CRITICAL. The port-B hub's loop is now paused from boot
    until register 0x0056 (the last proxied address) arrives with the status
    word in hand, with the receive buffer drained before release. Also corrects
    the feature-off log text: a declined read is answered with a device-failure
    exception, it was never si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
2026-10-01 PCB rev 1.1: EE review fixes
    -H4 (105 C) module C3013935; DE pull-downs R16/R17 so neither transceiver can
    drive the bus while the ESP is in reset or being flashed; 680R fail-safe bias
    (covers a terminated far end); F3 1.1 A / 33 V (a 0.5 A PPTC derates below
    any real fan at box temperature); 100 nF at the VDD pad; BOM grouped by part
    so no LCSC number spans two lines; header rotation keys fixed; JLC gerber set
    trimmed to fab layers. ERC 0, DRC 0 errors / 0 unconnected, 738 tracks / 109
    vias, pour plotted.
    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
    [binfohub_bridge-B_Courtyard.gbr, binfohub_bridge-B_Cu.gbr, binfohub_bridge-B_Fab.gbr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]
2026-10-01 CPL: WROOM rotation verified in JLC's viewer (needs 180, not 270)
    JLC's library zero has the antenna at -x; the raw board rotation put it at
    -y over the capacitor row. Confirmed in the placement preview: antenna at the
    board edge, pin 1 at (71.26, 53.25). SS14 and TS-1187A matched as-is.
    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
    [cpl_jlc.csv]
